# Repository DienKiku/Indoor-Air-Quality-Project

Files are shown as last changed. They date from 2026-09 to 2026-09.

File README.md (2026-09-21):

# Indoor Air Quality (IAQ) & Energy Monitoring IoT System






An edge-computing Internet of Things (IoT) station designed for real-time indoor environmental quality monitoring and autonomous power management. Powered by an ultra-compact **ESP32-C3 Super Mini (RISC-V)** microcontroller, the device integrates multi-sensor environmental sensing (PM2.5, VOC, Temperature, Humidity, Pressure), on-device visual feedback (1.8" ST7735 TFT), local acoustic alerts, a rechargeable 2S Li-ion battery subsystem with real-time power telemetry (INA219), and cloud synchronization with **Google Firebase**.

---

## 1. System Architecture

The project follows a modular **Three-Tier IoT Architecture**:

```mermaid
flowchart TD
    subgraph Tier1["Tier 1: Sensor & Edge Node (ESP32-C3 Super Mini)"]
        Sensors["Sensors:<br/>- BME680 (Temp, Hum, Press, Gas/VOC via I2C)<br/>- Sharp GP2Y1010AU0F (PM2.5 Dust via ADC + I-LED)<br/>- INA219 (Battery V, I, P via I2C)"]
        MCU["ESP32-C3 Super Mini<br/>(32-bit RISC-V @ 160MHz, 4MB Flash)"]
        Display["1.8-inch ST7735 TFT Display (SPI)"]
        Alert["TMB09A05 5V Buzzer (GPIO)"]
        PowerSubsystem["2S Li-ion Battery (2x 18650 2600mAh)<br/>- 2S 5A BMS Protection<br/>- Type-C 2S Boost Charger (8.4V)<br/>- AMS1117-5.0V LDO Regulator"]
        
        PowerSubsystem -->|"7.4V - 8.4V"| INA219
        INA219 -->|"V_bus / I_shunt"| AMS1117
        AMS1117 -->|"5.0V"| MCU
        AMS1117 -->|"5.0V"| Alert
        AMS1117 -->|"5.0V"| Sensors
        Sensors -->|"Data"| MCU
        MCU -->|"Render UI"| Display
        MCU -->|"Acoustic Alarm"| Alert
    end

    subgraph Tier2["Tier 2: Cloud Middleware (Google Firebase)"]
        FirebaseRTDB[("Firebase Realtime Database<br/>(NoSQL JSON Tree)")]
        FirebaseAuth["Firebase Authentication<br/>(Token / Database Secret)"]
        FirebaseHosting["Firebase Hosting / CDN"]
        FirebaseRTDB --- FirebaseAuth
    end

    subgraph Tier3["Tier 3: User Dashboard & Presentation"]
        WebDashboard["Web Application Dashboard<br/>- Real-time Gauges & Charts<br/>- Battery Health & Power Draw<br/>- Pollution & Threshold Alerts"]
        MobileView["Responsive Mobile UI"]
    end

    MCU -->|"Wi-Fi 802.11 b/g/n / HTTPS / WSS"| FirebaseRTDB
    FirebaseRTDB -->|"WebSocket Real-time Stream"| WebDashboard
    FirebaseRTDB -->|"WebSocket Real-time Stream"| MobileView
```

---

## 2. Hardware Bill of Materials (BOM)

| Component | Specification / Model | Interface | Function / Purpose |
| :--- | :--- | :--- | :--- |
| **Microcontroller (MCU)** | ESP32-C3 Super Mini (4MB Flash, RISC-V @ 160MHz) | Wi-Fi / BLE | Core controller, sensor aggregation, cloud comms |
| **Environmental Sensor** | Bosch BME680 | I2C (0x77 / 0x76) | Ambient Temp, Relative Humidity, Pressure, Gas/VOC |
| **Particulate Sensor** | Sharp GP2Y1010AU0F | Analog ADC + Digital GPIO | PM2.5 Optical Dust Density detection |
| **Energy Monitor** | INA219 MCU-219 | I2C (0x40) | 2S Battery bus voltage, discharge current, power draw |
| **Display** | 1.8-inch TFT LCD (ST7735 controller, 128x160) | SPI | Local graphical dashboard and status readouts |
| **Acoustic Indicator** | TMB09A05 5V Active Buzzer (9x5.5mm) | GPIO (via Transistor) | Audible alarms for hazardous IAQ and low battery |
| **Battery Cells** | 2x 18650 Li-ion Cells (2600 mAh each in 2S1P) | Battery Holder | Portable power source (Nominal: 7.4V, Full: 8.4V) |
| **Battery Management** | 2S 5A Lithium Protection Board (BMS) | Direct Battery | Overcharge, over-discharge, overcurrent & short-circuit protection |
| **Charger Board** | Type-C 3-6V to 2S-2A (8.4V) Boost Charger | USB Type-C | Fast, universal USB-C charging for 2S pack |
| **Voltage Regulator** | AMS1117-5.0V LDO Module | Power Rail | Steps down 7.4-8.4V battery output to stable 5.0V |

---

## 3. Hardware Circuit Schematic

The circuit schematic has been designed in KiCad and verified on physical prototype board:

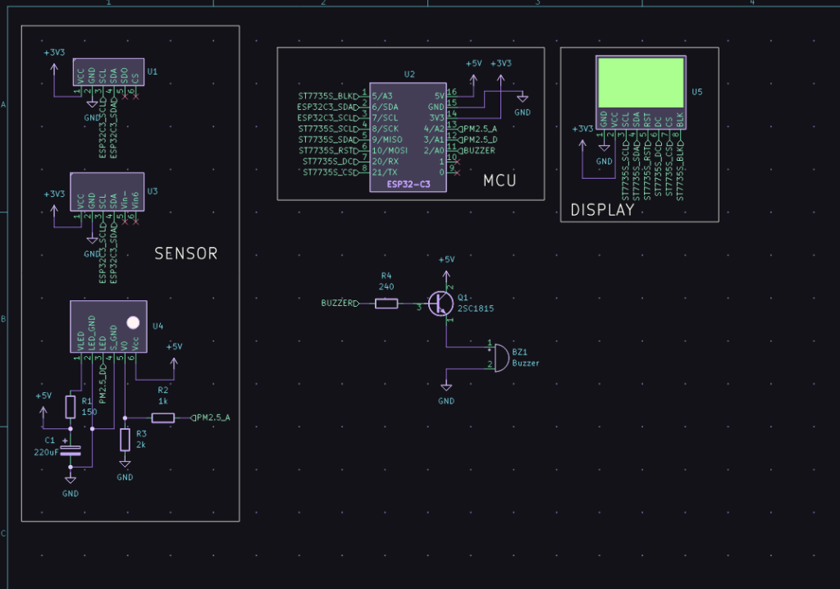
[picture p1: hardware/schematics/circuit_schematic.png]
Hardware Circuit Schematic


> **KiCad Design Source Files:** Available in [`hardware/schematics/`](hardware/schematics/) (`1.kicad_sch`, `1.kicad_pro`, `New_Library_1.kicad_sym`).

---

## 4. Repository Structure & Documentation

This repository is organized into distinct functional directories:

```text
├── hardware/
│   └── schematics/                # KiCad CAD schematic & visual diagram
│       ├── 1.kicad_sch            # KiCad schematic source file
│       ├── 1.kicad_pro            # KiCad project file
│       └── circuit_schematic.png  # Rendered KiCad schematic image
├── docs/
│   ├── system-spec/               # Technical system specifications
│   │   ├── 01_system_architecture.md
│   │   ├── 02_hardware_specification.md
│   │   ├── 03_circuit_and_pinout.md
│   │   ├── 04_software_and_cloud_spec.md
│   │   └── 05_power_management.md
│   ├── roadmap/                   # Project planning, Gantt, and RACI
│   │   ├── timeline_and_milestones.md
│   │   ├── task_assignment_raci.md
│   │   └── progress_tracker.md
│   ├── weekly-reports/            # Weekly progress tracking
│   │   ├── week-01.md
│   │   ├── week-02.md
│   │   └── week-03.md
│   └── reports/                   # Academic & Engineering Project Reports
│       ├── chapter_1_introduction.md
│       ├── chapter_2_theoretical_background.md
│       ├── chapter_3_hardware_software_design.md
│       ├── chapter_4_implementation_testing.md
│       └── chapter_5_conclusion_future_work.md
└── src/
    ├── firmware/                  # ESP32-C3 Arduino firmware (firmware.ino, firebase_config.h)
    ├── cloud-firebase/            # Firebase RTDB rules and sample telemetry schemas
    └── frontend/                  # Web Dashboard application (HTML5/CSS3/JS, Chart.js)
```

---

## 5. Software & Cloud Subsystems

- **ESP32-C3 Firmware ([`src/firmware/`](src/firmware/)):** The core firmware sketch ([`firmware.ino`](src/firmware/firmware.ino)) coordinates sensor acquisitions, ST7735 TFT graphical rendering (4-panel UI), 2S battery gauge monitoring, acoustic alarm triggering, and configured credentials ([`firebase_config.h`](src/firmware/firebase_config.h)). Can be edited and flashed using Arduino IDE or PlatformIO.
- **Cloud Backend ([`src/cloud-firebase/`](src/cloud-firebase/)):** Google Firebase Realtime Database schema and security rules for real-time station telemetry streaming.
- **User Web Dashboard ([`src/frontend/`](src/frontend/)):** Real-time monitoring dashboard ([`index.html`](src/frontend/index.html)) with live Chart.js trend visualization directly synced via Firebase WebSocket.

---

## 6. License
This project is licensed under the MIT License - see the [LICENSE](LICENSE) file for details.

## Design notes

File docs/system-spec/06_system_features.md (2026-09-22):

# System Features Specification

## 1. Indoor Air Quality (IAQ) Sensing Features
* **Real-time PM2.5 Fine Particulate Monitoring:**
  * Uses the Sharp GP2Y1010AU0F optical dust sensor[cite: 1].
  * Microsecond-accurate pulse driving circuit triggering an internal infrared LED with a $0.28\text{ ms}$ sampling window over a $0.32\text{ ms}$ cycle[cite: 1].
  * Internal analog-to-digital conversion (ADC) paired with a 10-sample moving average filter to suppress high-frequency noise and output dust density in $\mu\text{g/m}^3$.
* **Volatile Organic Compounds (VOC) & Gas Resistance Detection:**
  * Uses the Bosch BME680 sensor via standard I2C communication[cite: 1].
  * Dynamic metal-oxide (MOX) heated plate resistance measurement ($k\Omega$) for identifying smoke, solvent vapors, and gaseous pollutants[cite: 1].
* **Indoor Climate Telemetry (Temperature, Humidity, Pressure):**
  * Factory-calibrated ambient environmental acquisition via BME680 with high-precision outputs: temperature ($^\circ\text{C}$), relative humidity ($\%RH$), and barometric pressure ($\text{hPa}$)[cite: 1].

---

## 2. Power Subsystem & Energy Monitoring Features
* **Autonomous 2S Li-ion Battery Architecture:**
  * Powered by dual 18650 lithium-ion cells integrated with a 2S 5A BMS protection module against overcharge, over-discharge, and short circuits[cite: 1].
  * On-board Type-C 2S boost charging circuit supporting mobile charging up to $8.4\text{ V}$[cite: 1].
  * Regulated system bus powered via an AMS1117-5.0V low-dropout voltage regulator[cite: 1].
* **Real-time Battery Fuel Gauge & Power Profiling:**
  * High-side energy monitoring using the INA219 sensor via I2C (`0x40`)[cite: 1].
  * Real-time acquisition of bus voltage ($V$), shunt drop, and instantaneous discharge current ($mA$)[cite: 1].
  * Software-calculated battery State-of-Charge (SoC \%) and operating power consumption ($mW$)[cite: 1].

---

## 3. Local Graphical Display & Acoustic Alerting Features
* **Local Telemetry Dashboard (ST7735 1.8" TFT):**
  * Hardware 4-wire SPI graphical interface with dynamic UI partitioning[cite: 1].
  * 4-quadrant layout displaying: Temperature, Humidity, PM2.5 Dust Level, and VOC/Gas Index.
  * Real-time battery status icon with dynamic color coding based on charge level[cite: 1].
* **Multi-stage Acoustic Alarm System:**
  * Driven by a 5V active buzzer triggered via an NPN transistor switching circuit[cite: 1].
  * System startup and initialization feedback chirp[cite: 1].
  * Configurable acoustic alarm thresholds for dangerous PM2.5 concentrations, critical VOC levels, and low battery voltage[cite: 1].

---

## 4. Cloud Integration & Web Dashboard Features
* **Cloud Telemetry Streaming (Google Firebase):**
  * Automatic 2.4 GHz Wi-Fi connectivity on the ESP32-C3 with resilient auto-reconnect handling[cite: 1].
  * Structured JSON payload synchronization to Google Firebase Realtime Database (RTDB) every 5 seconds[cite: 1].
* **Interactive Responsive Web Dashboard:**
  * Browser-based user interface engineered using HTML5, CSS3, and modern vanilla JavaScript[cite: 1].
  * WebSocket real-time data streaming via the Firebase Web SDK for zero-refresh telemetry updates[cite: 1].
  * Dynamic time-series telemetry visualization utilizing Chart.js[cite: 1].
  * Historical trend analysis for ambient temperature, humidity, particulate density, and battery discharge curves.

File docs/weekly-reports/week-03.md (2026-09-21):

# Weekly Progress Report: Week 03

**Reporting Period:** 2026-09-15 to 2026-09-21  
**Project Name:** Indoor Air Quality (IAQ) & Energy Monitoring IoT System  
**Phase:** Phase 2: Hardware Prototyping & Sensor Validation  

---

## 1. Executive Summary
Week 03 achieved significant engineering milestones across hardware prototyping, electronic schematic capture, and offline firmware verification. A physical prototype circuit board was assembled and wired. The complete system schematic was designed in KiCad (`1.kicad_sch`) with custom footprint and symbol definitions. Offline firmware was developed and successfully executed on the hardware (`src/firmware/firmware.ino`), driving the 1.8-inch ST7735 TFT LCD with a custom 4-panel dashboard layout, active buzzer acoustics, and real-time telemetry from the Bosch BME680, Sharp GP2Y1010AU0F, and INA219 energy monitor.

---

## 2. Objectives for the Week
- [x] **Objective 1:** Assemble and wire the physical prototype circuit board.
- [x] **Objective 2:** Design and finalize the complete hardware schematic using KiCad.
- [x] **Objective 3:** Implement and validate standalone offline test firmware on the ESP32-C3.
- [x] **Objective 4:** Verify sensor data acquisition and graphical UI rendering on the 1.8" ST7735 TFT display.
- [x] **Objective 5:** Calibrate optical dust sensing with hardware scaling and validate INA219 power telemetry.
- [x] **Objective 6:** Prepare Google Firebase cloud schema and client configuration for Phase 3.

---

## 3. Accomplishments & Key Deliverables

### 3.1. Hardware Prototyping & KiCad Schematic
- Assembled the physical prototype board connecting:
  - ESP32-C3 Super Mini microcontroller.
  - Bosch BME680 (I2C: SDA on GPIO6, SCL on GPIO7).
  - INA219 Power Monitor (I2C: SDA on GPIO6, SCL on GPIO7).
  - Sharp GP2Y1010AU0F (IRED drive on GPIO3, Vo analog on GPIO4).
  - 1.8-inch ST7735 TFT LCD (SPI: CS on GPIO21, DC on GPIO20, RST on GPIO10, MOSI on GPIO9, SCLK on GPIO8, BL on GPIO5).
  - Acoustic Buzzer circuit driven by a 2SC1815 NPN transistor via GPIO2.
- Authored the complete electronic schematic in KiCad (`hardware/schematics/1.kicad_sch`, `1.kicad_pro`, `New_Library_1.kicad_sym`).
- Rendered high-resolution visual circuit diagram (`hardware/schematics/circuit_schematic.png`) for repository inspection.

### 3.2. Offline Test Firmware & Graphical UI
- Developed and verified `src/firmware/firmware.ino` on physical hardware:
  - Startup splash screen with system initialization check.
  - Acoustic double-chirp notification on boot (`BUZZER_PIN`).
  - 4-panel graphical layout on 128x160 TFT:
    - **TEMP Panel:** Displays temperature in °C; highlights RED (`COLOR_WARN`) when $> 35^\circ\text{C}$.
    - **HUMI Panel:** Displays relative humidity in %RH with green status.
    - **PM2.5 Panel:** Displays particulate mass concentration in $mg/m^3$; triggers alarm when $> 0.15 \, mg/m^3$.
    - **GAS Panel:** Displays BME680 gas resistance in $k\Omega$.
  - Bottom energy telemetry bar: Displays battery voltage (e.g., $7.9\text{V}$), discharge current (e.g., $88\text{mA}$), and dynamically draws a graphical 2S battery cell icon filled according to calculated SoC percentage.

### 3.3. Sensor Signal Calibration
- Integrated a $1.5\times$ scaling factor for the optical dust sensor analog output to account for the hardware resistor divider protecting the ESP32-C3 ADC.
- Implemented a 5-sample smoothing filter with $280\mu s$ pulse delay and $40\mu s$ sampling window.
- Formulated linear 2S State-of-Charge (SoC) calculation ($6.0\text{V} - 8.4\text{V}$).

---

## 4. Key Metrics & Test Results

| Test Scenario | Target Parameter | Measured Value | Result |
| :--- | :--- | :--- | :---: |
| **I2C Bus Scan** | BME680 & INA219 detection | Both devices acknowledged | **PASS** |
| **Display SPI Clock** | ST7735 rendering speed | Clean frame update @ 2s interval | **PASS** |
| **Optical Dust Sensor** | Baseline voltage in ambient air | $\approx 0.6V - 0.9V$ scaled | **PASS** |
| **Power Telemetry** | INA219 bus voltage reading | Matches multimeter within $\pm 0.02V$ | **PASS** |
| **Acoustic Alarm** | Buzzer trigger on $PM_{2.5} > 0.15$ | Sounds $200ms$ warning beep | **PASS** |

---

## 5. Challenges, Impediments & Mitigations

| Challenge / Issue | Root Cause | Mitigation / Solution |
| :--- | :--- | :--- |
| **Dust sensor Vo exceeding 3.3V** | Sharp GP2Y1010AU0F runs at 5V, outputting up to ~4.5V under heavy dust | Added a resistor voltage divider to step down the signal to $\le 3.3V$, and added a $1.5\times$ software correction factor in ADC calculation. |
| **LaTeX KaTeX error on GitHub** | MathJax parse conflict with unescaped `%` and multi-line `cases` in documentation | Re-formulated the SoC equation as a compact clamped piecewise formula, ensuring 100% flawless GitHub rendering. |

---

## 6. Objectives for Next Week (Week 04)
- [ ] **Objective 1:** Connect ESP32-C3 to local Wi-Fi and establish real-time link with Google Firebase Realtime Database.
- [ ] **Objective 2:** Configure Firebase project credentials (`FIREBASE_HOST`, `FIREBASE_AUTH`) and verify cloud JSON payload delivery.
- [ ] **Objective 3:** Integrate Firebase cloud data synchronization into the primary firmware sketch (`src/firmware/firmware.ino`).
- [ ] **Objective 4:** Test initial Web Dashboard connection to Firebase Realtime Database stream.

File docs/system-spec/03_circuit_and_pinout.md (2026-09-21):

# 03. Circuit Schematics & Pinout Mapping

## 1. Visual Circuit Schematic Diagram

Below is the complete hardware schematic diagram generated from the verified KiCad engineering schematic (`hardware/schematics/1.kicad_sch`):

Hardware Circuit Schematic

---

## 2. Verified Pin Assignment Table

The hardware prototype board connects the ESP32-C3 Super Mini to all peripherals using the verified pin mapping below:

| ESP32-C3 Pin | Connected Peripheral | Peripheral Pin | Interface / Protocol | Functional Description |
| :--- | :--- | :--- | :--- | :--- |
| **GPIO 6** | BME680 & INA219 | SDA | Hardware I2C (SDA) | Shared bi-directional I2C serial data line |
| **GPIO 7** | BME680 & INA219 | SCL | Hardware I2C (SCL) | Shared I2C serial clock line |
| **GPIO 9** | 1.8" ST7735 TFT | SDA / MOSI | Hardware SPI (MOSI) | Serial display pixel data input |
| **GPIO 8** | 1.8" ST7735 TFT | SCL / SCK | Hardware SPI (SCK) | Serial display clock signal |
| **GPIO 21** | 1.8" ST7735 TFT | CS | Digital Output (SPI CS) | Display active-low chip select |
| **GPIO 20** | 1.8" ST7735 TFT | DC / A0 | Digital Output (Data/Cmd)| Data/Command selection pin |
| **GPIO 10** | 1.8" ST7735 TFT | RES / RST | Digital Output (Reset) | Display hardware reset line |
| **GPIO 5** | 1.8" ST7735 TFT | BLK / LED | Digital Output / PWM | Backlight enable & brightness control |
| **GPIO 3** | Sharp GP2Y1010AU0F | Pin 3 (LED) | Digital Output (Active LOW)| Pulses infrared emitting diode (IRED) |
| **GPIO 4** | Sharp GP2Y1010AU0F | Pin 5 ($V_o$) | Analog Input (ADC1_CH4) | Scaled analog voltage from optical dust chamber |
| **GPIO 2** | Acoustic Buzzer Circuit| Base of Q1 (2SC1815)| Digital Output (HIGH=ON)| Drives active buzzer via NPN transistor |
| **5V (VIN)** | AMS1117-5.0V LDO | VOUT | Power Input (+5.0V) | Main regulated power rail to MCU board |
| **3.3V** | BME680, INA219, TFT | VCC / VDD | Power Rail (+3.3V) | Logic supply rail from ESP32-C3 onboard LDO |
| **GND** | All Modules | GND | Common System Ground | Common 0V reference ground across all circuits |

---

## 3. Sensor Interfacing Schematics

### 3.1. Sharp GP2Y1010AU0F Wiring
The Sharp GP2Y1010AU0F requires an external RC pulse driving network and a voltage divider:
- **Pin 1 ($V_{LED}$):** Connected to +5V through a $150 \Omega$ or $240 \Omega$ current-limiting resistor with a $220 \mu F$ bypass capacitor to GND.
- **Pin 2 ($LED\text{-}GND$):** Connected to Common GND.
- **Pin 3 ($LED$):** Connected to ESP32-C3 **GPIO 3** (`DUST_LED_PIN`). Driven LOW for $280\mu s$ before ADC sampling.
- **Pin 4 ($S\text{-}GND$):** Connected to Common GND.
- **Pin 5 ($V_o$):** Analog output voltage, routed through a resistive voltage divider to scale to $\le 3.3V$ and read via ESP32-C3 **GPIO 4** (`DUST_VO_PIN`).
- **Pin 6 ($V_{cc}$):** Connected to +5V regulated rail.

```
       +5V Rail -------------------+
                                   |
                                 [150R]
                                   |
                                   +------- Pin 1 (V_LED)
                                   |
                                 [220uF]
                                   |
       GND ------------------------+------- Pin 2 (LED-GND)
                                   |
       ESP32-C3 GPIO 1 -------------------- Pin 3 (LED Drive)
       GND -------------------------------- Pin 4 (S-GND)
       ESP32-C3 GPIO 0 (ADC) -------------- Pin 5 (V_o Output)
       +5V Rail --------------------------- Pin 6 (V_cc)
```

### 2.2. INA219 Power Sense Wiring
- **VIN+:** Connected to the positive terminal of the 2S 5A BMS output ($7.4V - 8.4V$).
- **VIN-:** Connected to the input of the AMS1117-5.0V voltage regulator.
- **VCC:** Connected to 3.3V rail.
- **GND:** Connected to Common GND.
- **SDA:** Connected to ESP32-C3 **GPIO 8**.
- **SCL:** Connected to ESP32-C3 **GPIO 9**.

### 2.3. Active Buzzer Circuit (TMB09A05)
Because the ESP32-C3 GPIO pins supply up to ~20 mA at 3.3V and the TMB09A05 requires 5V with ~30-40 mA peak current, an NPN switching transistor (2N2222 or SS8050) is used:
- **Collector:** Connected to Buzzer negative pin (-).
- **Buzzer positive pin (+):** Connected to +5V rail.
- **Emitter:** Connected to Common GND.
- **Base:** Connected to ESP32-C3 **GPIO 2** through a $1 k\Omega$ current-limiting resistor.
- A flyback diode (1N4148) is placed in anti-parallel across the buzzer terminals to suppress inductive voltage spikes.

---

## 3. Power Distribution Diagram

```
[USB Type-C 5V Input]
         |
         v
[Type-C to 2S 8.4V Boost Charger]
         |
         v
[2x 18650 Li-ion Cells (2S1P)] <---> [2S 5A BMS Board]
                                              |
                                              v  Pack Output (7.4V - 8.4V)
                                       [INA219 Sense (VIN+ -> VIN-)]
                                              |
                                              v
                                      [AMS1117-5.0V Module]
                                              |
                      +-----------------------+-----------------------+
                      | 5.0V Rail                                     | 5.0V Rail
                      v                                               v
            [ESP32-C3 VIN pin]                             [GP2Y1010AU0F & Buzzer]
                      |
                      v (On-board LDO)
                 3.3V Logic Rail
                      |
        +-------------+-------------+
        |                           |
        v                           v
  [Bosch BME680]          [ST7735 1.8" TFT]
```

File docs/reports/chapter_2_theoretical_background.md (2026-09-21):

# Chapter 2: Theoretical Background & System Design

## 2.1. Indoor Air Quality (IAQ) Metrics & International Standards

Indoor Air Quality (IAQ) refers to the chemical, physical, and biological characteristics of air within buildings and structures as they relate to the health, comfort, and productivity of occupants. Evaluating IAQ requires quantifying multiple independent airborne metrics against established environmental health guidelines.

### 2.1.1. Fine Particulate Matter ($PM_{2.5}$ and $PM_{10}$)
Particulate matter represents a complex mixture of microscopic solid particles and liquid droplets suspended in the air. Particles are categorized by their aerodynamic diameter:
- **Coarse Particulates ($PM_{10}$):** Particles with diameters between $2.5 \, \mu m$ and $10 \, \mu m$ (e.g., pollen, coarse dust, mold spores).
- **Fine Particulates ($PM_{2.5}$):** Particles with aerodynamic diameters $\le 2.5 \, \mu m$ (e.g., combustion particles, organic compounds, heavy metals).

Because $PM_{2.5}$ particles remain suspended in ambient air for prolonged durations and readily penetrate deep into the alveolar regions of the human respiratory system, international regulatory bodies enforce stringent thresholds. The World Health Organization (WHO) and the United States Environmental Protection Agency (US-EPA) define air quality rating categories based on 24-hour average $PM_{2.5}$ concentrations:

| EPA Air Quality Category | $PM_{2.5}$ Concentration Range ($\mu g/m^3$) | Health Implications for Occupants |
| :--- | :---: | :--- |
| **Good** | $0.0 - 12.0$ | Air quality is considered satisfactory; air pollution poses little or no risk. |
| **Moderate** | $12.1 - 35.4$ | Acceptable air quality; slight risk for unusually sensitive individuals. |
| **Unhealthy for Sensitive Groups** | $35.5 - 55.4$ | Members of sensitive groups may experience respiratory irritation. |
| **Unhealthy** | $55.5 - 150.4$ | General public may begin to experience health effects; sensitive groups affected more severely. |
| **Very Unhealthy / Hazardous** | $\ge 150.5$ | Health alert: serious risk of respiratory and cardiovascular impairment for all occupants. |

### 2.1.2. Volatile Organic Compounds (VOCs)
Volatile Organic Compounds encompass a diverse class of carbon-based chemicals exhibiting high vapor pressure under standard room temperatures ($20^\circ C - 25^\circ C$). Common indoor VOCs include formaldehyde ($HCHO$), benzene ($C_6H_6$), toluene, and ethanol. Total Volatile Organic Compound (TVOC) concentration serves as a vital index for chemical indoor air quality. Prolonged exposure causes irritation of the eyes and respiratory tract, chronic headaches, and increased long-term oncological risks.

### 2.1.3. Microclimate Variables: Temperature, Humidity, and Pressure
Ambient thermal parameters directly influence chemical off-gassing rates and biological contamination:
- **Temperature ($T$):** Elevated indoor temperatures accelerate the evaporation and emission rates of VOCs from building materials.
- **Relative Humidity ($RH$):** High humidity ($RH > 65\%$) creates an ideal environment for mold propagation, dust mite proliferation, and bacterial colonization, whereas low humidity ($RH < 30\%$) irritates respiratory mucous membranes.
- **Barometric Pressure ($P$):** Atmospheric pressure gradients govern air infiltration rates between indoor zones and outdoor air.

---

## 2.2. Sensing Principles & Transducer Technologies

### 2.2.1. Optical Particulate Detection: Sharp GP2Y1010AU0F
The Sharp GP2Y1010AU0F dust sensor employs the **light scattering principle**. Inside the optical chamber, an Infrared Emitting Diode (IRED) and a phototransistor are positioned diagonally.

```
       [IRED Pulse Generator] 
                 \
                  \  Incident IR Beam (lambda = 850nm)
                   \
               [Dust Particles] ---> Scattered Light Rays
                     \
                      \  Scattered Beam
                       v
              [Phototransistor Receiver]
                       |
                       v
         [Signal Conditioning Amplifier]
                       |
                       v
           Analog Output Voltage (V_o)
```

1. **Pulse Activation:** When the internal IRED is pulsed with a narrow forward current pulse, an infrared light beam traverses the sensing chamber.
2. **Rayleigh/Mie Scattering:** Suspended dust particles crossing the optical path scatter light at an angle proportional to particle surface area and density.
3. **Phototransistor Detection:** The phototransistor collects a portion of the scattered light, generating a photocurrent that is internally amplified into an analog output voltage $V_o$.
4. **Timing Constraints:** To prevent thermal drift and minimize power consumption, the IRED must be pulsed with strict timing:
   - Pulse period $T = 10 \, ms$.
   - Pulse duration $\tau = 0.32 \, ms$ ($320 \, \mu s$).
   - Sampling instant $t_{sample} = 0.28 \, ms$ ($280 \, \mu s$) from pulse initiation.
5. **Transfer Function & Hardware Scaling:** Because the sensor output $V_o$ can reach $\approx 4.5V - 5.0V$, a resistive voltage divider steps the signal down to the ESP32-C3 ADC range ($\le 3.3V$), introducing a scaling correction factor of $1.5\times$:
   $$V_{Vo} = V_{ADC} \times 1.5$$
   The calibrated particulate mass concentration $D$ (in $\text{mg/m}^3$) is calculated as:
   $$D \, (\text{mg/m}^3) = \max\left(0.0, \; 0.17 \times V_{Vo} - 0.1\right)$$
   and converted to standard $\mu\text{g/m}^3$ via:
   $$D \, (\mu\text{g/m}^3) = D \, (\text{mg/m}^3) \times 1000$$

### 2.2.2. Metal Oxide Semiconductor (MOX) Gas Sensing: Bosch BME680
The BME680 integrates an ambient temperature sensor, capacitive humidity sensor, piezoresistive barometric pressure sensor, and a metal-oxide (MOX) gas sensor onto a single monolithic silicon die.

- **Operating Principle:** The gas sensor utilizes a heated thin-film layer of metal oxide semiconductor (typically tin dioxide, $SnO_2$). In clean ambient air, atmospheric oxygen molecules adsorb onto the $SnO_2$ crystal surface, capturing conduction-band electrons to form negative surface oxygen ions ($O^-, O_2^-$). This forms a high-resistance potential barrier at inter-grain boundaries:
  $$O_2(gas) + 2e^- \rightarrow 2O^-(ads)$$
- **Reaction with Reducing VOC Gases:** When volatile organic compounds (e.g., ethanol, formaldehyde, carbon monoxide) contact the heated metal-oxide surface ($300^\circ C - 320^\circ C$), they react with the adsorbed oxygen ions, releasing captured electrons back into the conduction band:
  $$R\text{-}H + O^-(ads) \rightarrow R\text{-}OH + e^-$$
- **Resistance Reduction:** This electron release diminishes the potential barrier, causing a sharp reduction in electrical resistance across the sensor film ($R_{gas}$). The measured resistance $R_{gas}$ is inversely related to VOC concentration.

### 2.2.3. High-Side Shunt Energy Monitoring: INA219
The Texas Instruments INA219 is a high-side current shunt and power monitor with an I2C interface.

```
       V_bat (+) ------+--------------------+------ Load Rail (AMS1117-5.0V)
                       |                    |
                     [VIN+]               [VIN-]
                       |                    |
                       +-----[ R_shunt ]----+  (R_shunt = 0.1 Ohm)
                                  |
                                  v
                     [Differential PGA (x1 - x8)]
                                  |
                                  v
                     [12-bit Delta-Sigma ADC]
                                  |
                                  v
                     [Internal Digital Multiplier]
                                  |
                                  v
                        [I2C Register Interface]
```

- **Shunt Voltage Measurement:** Measures the differential voltage drop across a precision shunt resistor ($R_{shunt} = 0.1 \, \Omega$, 1% tolerance) inserted in series between the battery positive terminal and the load:
  $$V_{shunt} = V_{IN+} - V_{IN-}$$
- **Current Derivation:** Current is computed digitally inside the INA219:
  $$I = \frac{V_{shunt}}{R_{shunt}}$$
- **Bus Voltage Measurement:** The voltage between the $V_{IN-}$ pin and system ground ($GND$) represents the actual battery bus voltage $V_{bus}$.
- **Power Derivation:** Instantaneous system power is calculated as:
  $$P = V_{bus} \times I$$

---

## 2.3. Microcontroller Architecture: ESP32-C3 Super Mini

The central processing unit of the monitoring station is the **ESP32-C3 Super Mini**, an ultra-low-power, high-performance System-on-Chip (SoC) developed by Espressif Systems:
- **Processor Core:** 32-bit RISC-V single-core microprocessor (RV32IMC instruction set architecture) operating at clock frequencies up to $160 \, MHz$.
- **Memory Subsystem:**
  - $400 \, KB$ of internal SRAM for data storage and dynamic memory allocation.
  - $384 \, KB$ of internal ROM for booting and core library routines.
  - $4 \, MB$ of external Quad-SPI Flash memory integrated on-module for firmware code, assets, and configuration.
- **Wireless Networking:**
  - Integrated 2.4 GHz Wi-Fi subsystem compliant with IEEE 802.11 b/g/n, supporting HT20/HT40 bandwidths with data rates up to $150 \, Mbps$.
  - Bluetooth 5 (LE) supporting 2 Mbps PHY, long range, and broadcast advertising.
- **Integrated Hardware Peripherals:**
  - 12-bit Successive Approximation Register (SAR) Analog-to-Digital Converter (ADC) across multiple channels.
  - Hardware I2C master controller supporting standard ($100 \, kHz$) and fast ($400 \, kHz$) modes.
  - General-Purpose SPI controller capable of high-speed transmission up to $40 \, MHz$, critical for smooth TFT display refreshing.
  - General-Purpose Input/Output (GPIO) matrix with configurable pull-up, pull-down, and drive strengths.

---

## 2.4. Cloud Middleware & Synchronization: Google Firebase

To deliver real-time data streaming and remote dashboard access without managing dedicated server infrastructure, the platform leverages **Google Firebase**:

```
[ESP32-C3 Edge Node] 
        |
        | Secure TLS / HTTPS / WebSocket Stream
        v
[Firebase Realtime Database (RTDB)] <--- NoSQL JSON Tree
        |
        | Server-Sent Events (SSE) / WebSocket Push
        v
[Client Web Dashboard (HTML5/JS)]
```

1. **Firebase Realtime Database (RTDB):** A cloud-hosted NoSQL document database where data is structured as a single hierarchical JSON tree. Unlike traditional SQL databases that require polling, Firebase pushes updates to connected clients in real time over persistent WebSocket connections.
2. **Low-Latency Bi-Directional Synchronization:** When the ESP32-C3 executes a `setJSON()` or `updateNode()` operation, the updated environmental state is propagated to all open web dashboard instances within milliseconds.
3. **Offline Caching & Data Resiliency:** The client-side Firebase JavaScript SDK provides local caching capabilities, maintaining seamless dashboard interactivity during intermittent network disconnects.
4. **Security Enforcement:** Declarative JSON security rules govern read/write permissions, validating that incoming sensor payloads adhere to expected schema definitions and type constraints.

---

## 2.5. Autonomous Power Subsystem & Energy Modeling

### 2.5.1. 2S Li-ion Battery Configuration
To provide untethered mobility, the system is powered by two cylindrical Lithium-ion 18650 cells connected in series (2S1P configuration):
- **Nominal Pack Voltage:** $2 \times 3.7V = 7.4V$.
- **Full Charge Pack Voltage:** $2 \times 4.2V = 8.4V$.
- **Cutoff / Depleted Pack Voltage:** $2 \times 3.0V = 6.0V$.
- **Nominal Cell Capacity:** $2600 \, mAh$ ($2.6 \, Ah$).
- **Total Pack Energy:**
  $$E = V_{nominal} \times C = 7.4V \times 2.6Ah = 19.24 \, \text{Wh}$$

### 2.5.2. Battery Management System (BMS 2S 5A)
Lithium-ion cells require active electronic protection against hazardous operating regimes:
- **Overcharge Cutoff ($V_{ovp}$):** $4.25V \pm 0.05V$ per cell. Disconnects charging current to prevent thermal runaway.
- **Over-discharge Cutoff ($V_{uvp}$):** $2.50V \pm 0.08V$ per cell. Disconnects the load to protect cell chemistry against irreversible copper dissolution.
- **Overcurrent Protection:** Automatically interrupts conduction if discharge current exceeds $10A$ peak or $5A$ continuous.

### 2.5.3. Type-C 2S Boost Charger (8.4V, 2A)
The charger board utilizes a high-efficiency synchronous boost switching converter:
- Converts standard $5.0V$ USB input (from smartphone chargers or power banks) up to the $8.4V$ required for 2S charging.
- Executes the standard two-phase **Constant Current / Constant Voltage (CC/CV)** charging profile:
  - **CC Phase:** Delivers up to $2.0A$ constant current while the pack voltage rises from $6.0V$ toward $8.4V$.
  - **CV Phase:** Maintains exactly $8.40V$ while charging current exponentially decays to the termination threshold ($C/10 \approx 200mA$).

### 2.5.4. Linear Voltage Regulation: AMS1117-5.0V
The AMS1117-5.0V Low Dropout (LDO) regulator steps down the variable battery pack voltage ($7.4V - 8.4V$) to a stable $5.0V$ rail:
- Supplies the Sharp GP2Y1010AU0F optical dust sensor ($5V \pm 10\%$).
- Supplies the TMB09A05 active buzzer ($5V$).
- Feeds the $VIN$ pin of the ESP32-C3 Super Mini, whose internal onboard LDO further steps down $5.0V$ to $3.3V$ for the RISC-V core, BME680, and ST7735 logic.
- **LDO Efficiency:**
  $$\eta_{LDO} = \frac{V_{out}}{V_{in}} = \frac{5.0V}{7.4V} \approx 67.5\% \quad (\text{at nominal battery voltage})$$
  Power dissipated as heat:
  $$P_{diss} = (V_{in} - V_{out}) \times I_{load} = (7.4V - 5.0V) \times 0.15A \approx 0.36 \, W$$

---

## 2.6. Proposed System Architecture & Design

The functional architecture integrates the sensing transducers, edge processing, visual/acoustic alerting, and cloud synchronization into an interdependent pipeline:

```mermaid
flowchart TD
    subgraph Power["Power Subsystem (2S)"]
        Bat["2x 18650 Li-ion Cells (7.4V)"] --> BMS["2S 5A BMS Board"]
        BMS --> INA["INA219 Current/Voltage Monitor"]
        INA --> LDO["AMS1117-5.0V Regulator"]
        LDO --> Rail5V["5.0V Power Rail"]
    end

    subgraph Sensing["Sensing Layer"]
        BME["Bosch BME680 (I2C)"]
        Dust["Sharp GP2Y1010AU0F (ADC/GPIO)"]
    end

    subgraph Processing["ESP32-C3 Super Mini Core"]
        Sample["Sensor Acquisition Loop"]
        Filter["Moving Average Filter & Baseline Tracker"]
        Eval["Threshold & IAQ Level Evaluation"]
        DisplayDriver["ST7735 SPI Display Driver"]
        CloudDriver["Firebase Client Sync Task"]
    end

    subgraph Output["Output & Presentation"]
        TFT["1.8-inch ST7735 TFT Display"]
        Buzzer["TMB09A05 Active Buzzer"]
        Firebase[("Google Firebase RTDB")]
        Dashboard["Web Application Dashboard"]
    end

    Rail5V --> Dust
    Rail5V --> Buzzer
    Rail5V --> Processing
    Processing -->|"3.3V Logic"| BME
    Processing -->|"3.3V Logic"| INA
    
    BME -->|"I2C: SDA/SCL"| Sample
    INA -->|"I2C: SDA/SCL"| Sample
    Dust -->|"Analog Vo & I-LED Pulse"| Sample
    
    Sample --> Filter --> Eval
    Eval --> DisplayDriver --> TFT
    Eval -->|"GPIO Trigger"| Buzzer
    Eval --> CloudDriver -->|"Wi-Fi / WSS"| Firebase
    Firebase -->|"WebSocket Push"| Dashboard
```

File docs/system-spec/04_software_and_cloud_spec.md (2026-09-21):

# 04. Software & Cloud Specification

## 1. Firmware Architecture (C/C++)

The firmware is developed using the **PlatformIO ecosystem** on the **Arduino Framework** for the ESP32-C3. The software executes a non-blocking, multi-interval scheduling loop to ensure timely sensor sampling, local rendering, and network synchronization.

```mermaid
stateDiagram-v2
    [*] --> Initialization
    Initialization --> SensorCalibration : I2C & SPI Init
    SensorCalibration --> WiFiConnect : Connect to 2.4GHz AP
    WiFiConnect --> FirebaseAuth : Initialize Firebase Client
    FirebaseAuth --> MainLoop : Start Scheduler

    state MainLoop {
        [*] --> CheckTimers
        CheckTimers --> SampleDust : Every 1000ms
        CheckTimers --> SampleBME680 : Every 2000ms
        CheckTimers --> SampleINA219 : Every 2000ms
        CheckTimers --> UpdateTFT : Every 1000ms
        CheckTimers --> SyncFirebase : Every 5000ms
        CheckTimers --> EvaluateAlerts : Immediate
    }
```

---

## 2. Sensor Signal Processing Algorithms

### 2.1. Sharp GP2Y1010AU0F Microsecond Timing & Calibration
The optical dust sensor requires microsecond-accurate pulse modulation to energize the infrared emitter diode (IRED) and sample the scattered light:

1. Drive `GPIO 3` (DUST_LED_PIN) LOW to activate the internal IRED.
2. Wait precisely $280 \mu s$ ($0.28 ms$) for the light pulse and optical reflection to stabilize.
3. Sample the analog voltage on `GPIO 4` (DUST_VO_PIN) using the ESP32-C3 12-bit ADC (`ADC_11db` attenuation, sampling duration $\approx 40 \mu s$).
4. Drive `GPIO 3` HIGH to deactivate the IRED (total pulse duration: $320 \mu s$).
5. Wait for $9680 \mu s$ to complete the standard $10 ms$ operating cycle.

#### Mathematical Conversion & Hardware Scaling:
The analog output $V_o$ from the GP2Y1010AU0F can reach up to $\approx 4.5V - 5.0V$. A hardware resistor voltage divider is placed at the analog pin to scale the signal to within the ESP32-C3 ADC range ($\le 3.3V$), introducing a scaling correction factor of $1.5$:

$$V_{raw} = \text{ADC\_Value} \times \left(\frac{3.3\text{V}}{4095}\right)$$
$$V_{Vo} = V_{raw} \times 1.5$$

Applying the calibrated Sharp linear transfer function:
$$\text{Dust Density } (\text{mg/m}^3) = \max\left(0.0, \; 0.17 \times V_{Vo} - 0.1\right)$$

To convert to standard $\mu g/m^3$:
$$\text{Dust Density } (\mu\text{g/m}^3) = \text{Dust Density } (\text{mg/m}^3) \times 1000$$

A **5-sample Moving Average Filter (MAF)** is applied to smooth instantaneous noise:
$$\bar{D} = \frac{1}{5} \sum_{i=1}^{5} D_i$$

### 2.2. BME680 Gas Resistance & IAQ Estimation
The BME680 incorporates a metal-oxide (MOX) gas sensor heated to 320°C for 150 ms before readout. Higher gas resistance ($R_{gas}$ in $k\Omega$) indicates cleaner air, while lower resistance corresponds to elevated volatile organic compounds (VOCs).

- **Gas Resistance Formula:**
  $$R_{gas} (\text{k}\Omega) = \frac{\text{raw\_resistance}}{1000.0}$$
- **Categorization:**
  - $R_{gas} \ge 150 \, k\Omega$: Good (clean indoor air).
  - $50 \, k\Omega \le R_{gas} < 150 \, k\Omega$: Moderate.
  - $R_{gas} < 50 \, k\Omega$: Hazardous (Elevated VOC / cooking smoke / solvent vapors).

### 2.3. Battery State-of-Charge (SoC) Calculation
The INA219 measures the 2S battery pack bus voltage ($V_{bus}$). The remaining capacity percentage is calculated using a linear interpolation across the 2S operational range ($6.0\text{V}$ cutoff to $8.4\text{V}$ fully charged):

$$\text{Battery SoC (\%)} = \min\left(100, \; \max\left(0, \; \frac{V_{bus} - 6.0\text{V}}{8.4\text{V} - 6.0\text{V}} \times 100\right)\right)$$

In the firmware implementation:
```cpp
float batteryPct = (busvoltage - 6.0) / (8.4 - 6.0) * 100.0;
if (batteryPct > 100) batteryPct = 100;
if (batteryPct < 0) batteryPct = 0;
```

---

## 3. Google Firebase Cloud Specification

### 3.1. Database Architecture
Data is synchronized to the **Firebase Realtime Database (RTDB)** using an optimized JSON hierarchical structure:

```json
{
  "iaq_stations": {
    "ESP32C3_STATION_01": {
      "metadata": {
        "firmware_version": "1.0.0",
        "device_name": "Living Room Monitor",
        "last_seen": 1726848000
      },
      "live_metrics": {
        "temperature_c": 26.4,
        "humidity_pct": 58.1,
        "pressure_hpa": 1013.2,
        "gas_resistance_kohm": 142.5,
        "pm25_ug_m3": 18.3,
        "iaq_grade": "GOOD",
        "timestamp": 1726848000
      },
      "power_telemetry": {
        "bus_voltage_v": 7.94,
        "current_ma": 92.6,
        "power_mw": 735.2,
        "battery_pct": 81,
        "charging_state": false
      },
      "alerts": {
        "active": false,
        "type": "NONE",
        "message": "Air quality is optimal."
      },
      "history": {
        "-O7x9A1b2c3d4e5f": {
          "timestamp": 1726848000,
          "pm25": 18.3,
          "voc_kohm": 142.5,
          "temp": 26.4,
          "hum": 58.1,
          "v_bat": 7.94
        }
      }
    }
  }
}
```

### 3.2. Firebase Security Rules
Granular rules enforce that the ESP32-C3 can only write to its designated station node while authenticated:

```json
{
  "rules": {
    "iaq_stations": {
      "$station_id": {
        ".read": true,
        ".write": "auth != null || auth.uid === $station_id"
      }
    }
  }
}
```

---

## 4. Alert & Threshold Logic

| Parameter | Operational Threshold | Hardware Trigger | UI & System Action |
| :--- | :--- | :--- | :--- |
| **PM2.5 Dust** | $> 0.15 \, \text{mg/m}^3$ ($150 \, \mu\text{g/m}^3$) | `dustDensity > 0.15` | TFT text turns RED (`COLOR_WARN`); Buzzer sounds alert beep ($200\text{ms}$) |
| **Battery SoC** | $< 20.0\%$ ($V_{bus} < 6.48\text{V}$) | `batteryPct < 20.0` | Battery icon turns RED; Buzzer sounds low-power warning |
| **Temperature** | $> 35.0^\circ\text{C}$ | `temp > 35.0` | Temperature reading turns RED (`COLOR_WARN`) |
| **BME680 VOC** | $< 50.0 \, \text{k}\Omega$ | Low gas resistance | Environmental quality status degrades on TFT |

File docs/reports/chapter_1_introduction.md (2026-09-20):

# Chapter 1: Introduction

## 1.1. Background & Problem Statement

In modern urbanized societies, humans spend approximately 85% to 90% of their daily lives inside enclosed environments—including residences, educational institutions, offices, and commercial spaces. Consequently, the quality of indoor air significantly dictates human health, respiratory well-being, cognitive performance, and overall quality of life.

Despite widespread public awareness regarding outdoor atmospheric smog and industrial emissions, empirical environmental studies consistently reveal that **indoor air pollutant concentrations can be two to five times—and in severe cases up to one hundred times—higher than outdoor levels**. Indoor environments accumulate diverse airborne pollutants emitted from:
- Cooking activities, biomass combustion, and tobacco smoke, which release hazardous **Fine Particulate Matter ($PM_{2.5}$ and $PM_{10}$)**.
- Building materials, synthetic paints, adhesives, varnishes, and cleaning detergents, which emit a wide spectrum of **Volatile Organic Compounds (VOCs)** such as formaldehyde, benzene, and toluene.
- Human respiration in inadequately ventilated spaces, resulting in elevated carbon dioxide ($CO_2$) and stagnant humidity, fostering microbial colonies and mold growth.

Inhalation of fine particles with aerodynamic diameters $\le 2.5 \, \mu m$ ($PM_{2.5}$) poses acute and chronic health risks. Due to their minute dimensions, $PM_{2.5}$ particles bypass upper respiratory filtration mechanisms, penetrating deep into the pulmonary alveoli and entering the systemic bloodstream. Long-term exposure correlates directly with chronic obstructive pulmonary disease (COPD), ischemic heart disease, stroke, and lung cancer. Concurrently, elevated concentrations of VOCs induce "Sick Building Syndrome" (SBS), characterized by headaches, mucous membrane irritation, fatigue, and impaired cognitive clarity.

---

## 1.2. Motivation & Significance

While commercial consumer air purifiers and standalone monitors exist on the market, they present several critical engineering and operational limitations:
1. **Proprietary Ecosystems & Data Silos:** Commercial units often restrict data access to proprietary cloud silos with closed communication protocols, precluding integration into open-source building management systems or customized analytical platforms.
2. **Limited Multi-Parameter Sensing:** Low-cost monitors typically detect only a single parameter (e.g., temperature and humidity, or dust alone), failing to deliver a holistic indoor air quality (IAQ) assessment that combines fine particulates, chemical gases (VOCs), and barometric microclimate variables.
3. **Lack of Autonomous Power Telemetry:** Portable monitoring nodes deployed in dynamic indoor environments require untethered battery operation. However, existing devices lack integrated high-precision power telemetry, leaving users unable to predict remaining runtime or manage energy consumption effectively.

To address these challenges, this project designs and implements an open, edge-computing **Indoor Air Quality (IAQ) and Energy Monitoring IoT System**. By combining an ultra-low-power 32-bit RISC-V microcontroller (ESP32-C3) with laboratory-grade multi-sensor instrumentation (Bosch BME680, Sharp GP2Y1010AU0F, INA219), a full-color graphical display (ST7735), an autonomous 2S Li-ion battery subsystem, and real-time cloud synchronization via **Google Firebase**, this system provides a comprehensive, cost-effective, and fully verifiable indoor environmental management solution.

---

## 1.3. Research Objectives & System Scope

### 1.3.1. Primary Objectives
The primary aim of this project is to develop, validate, and evaluate an autonomous, IoT-enabled indoor environmental monitoring station. Specific technical objectives include:
1. **Multi-Parameter Environmental Sensing:** Design and interface sensory circuits capable of measuring particulate matter ($PM_{2.5}$), total volatile organic compounds (VOC gas resistance), ambient temperature, relative humidity, and atmospheric pressure.
2. **Autonomous Power Management & Energy Telemetry:** Architect a self-contained 2S Li-ion battery power subsystem featuring overcharge/over-discharge protection (BMS), USB Type-C boost charging, linear voltage regulation, and real-time high-side current and voltage sensing via the INA219 transducer.
3. **Edge Signal Processing & Local Alerting:** Implement digital filtering algorithms (10-sample moving average) for analog optical dust sensing, dynamic baseline calibration for MOX gas resistance, on-device rendering on a 1.8-inch TFT LCD, and acoustic alarm generation for hazardous conditions.
4. **Real-time Cloud Integration & User Dashboard:** Establish secure Wi-Fi connectivity to synchronize telemetry data to Google Firebase Realtime Database and build a responsive Web Dashboard with live visual gauges, time-series charts, and historical analytics.

### 1.3.2. Scope and Delimitations
- **Deployment Domain:** The system is engineered for indoor domestic, office, and academic laboratory spaces (enclosed areas ranging from $15 \, m^2$ to $60 \, m^2$).
- **Target Particulate Range:** Optical detection of $PM_{2.5}$ dust concentrations between $0 \, \mu g/m^3$ and $500 \, \mu g/m^3$.
- **Target Microclimate Range:** Ambient temperature (-10°C to +60°C), relative humidity (10% to 90% RH), and barometric pressure (300 hPa to 1100 hPa).
- **Network Constraints:** Requires a standard 2.4 GHz IEEE 802.11 b/g/n Wi-Fi local access point with Internet connectivity for cloud synchronization.

---

## 1.4. Methodology & Engineering Approach

The project adheres to an iterative hardware-software co-design methodology:
1. **Theoretical Formulation:** Mathematical modeling of optical dust scattering, metal-oxide semiconductor gas reaction kinetics, and battery State-of-Charge (SoC) estimation.
2. **Hardware Design & Prototyping:** Breadboard assembly, verification of electrical signal integrity across SPI and I2C buses, design of the optical sensor RC pulse network, and validation of the 2S battery protection circuit.
3. **Firmware Engineering:** Modular C/C++ development utilizing PlatformIO, implementing non-blocking cooperative scheduling to coordinate sensor sampling, graphical rendering, and network synchronization.
4. **Cloud Infrastructure & Frontend Development:** Configuration of Google Firebase Realtime Database schema and security rules, paired with an asynchronous web dashboard developed using HTML5, CSS3, JavaScript, and Chart.js.
5. **Experimental Validation:** Comprehensive empirical testing including sensor baseline calibration, power consumption profiling across operational states, and battery autonomy benchmarking.

---

## 1.5. Report Organization

The remainder of this report is organized as follows:
- **Chapter 2: Theoretical Background & System Design** details the scientific principles of indoor air quality metrics, sensing transducer technologies, embedded RISC-V architectures, Firebase cloud mechanics, and the overall system design.
- **Chapter 3: Detailed Hardware & Software Design** describes the schematic design, PCB layout, pinout assignments, C/C++ firmware state machines, and web application architecture.
- **Chapter 4: Implementation & Experimental Evaluation** presents the physical assembly, calibration procedures, experimental results, power efficiency benchmarks, and system validation.
- **Chapter 5: Conclusion & Future Work** summarizes the major engineering contributions, discusses system limitations, and outlines future enhancements.

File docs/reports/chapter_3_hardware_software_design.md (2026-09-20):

# Chapter 3: Detailed Hardware & Software Design

## 3.1. Hardware Schematic & Interfacing Design
- **3.1.1. Power Distribution Network:** Integration of 2S Li-ion pack, BMS protection, INA219 shunt sensing, AMS1117-5.0V LDO, and decoupling capacitor placement ($10\mu F$ and $0.1\mu F$ ceramic capacitors).
- **3.1.2. ESP32-C3 Super Mini Pin Allocation:** Detailed hardware pinout mapping, GPIO strapping pin constraints (GPIO2, GPIO8, GPIO9), and pull-up resistor values.
- **3.1.3. Optical Dust Sensor Interface:** Design of the external $150\Omega$ resistor and $220\mu F$ electrolytic capacitor pulse circuit for the Sharp GP2Y1010AU0F.
- **3.1.4. I2C Bus Topology:** Multi-device bus configuration accommodating Bosch BME680 (`0x77`) and INA219 (`0x40`) with 4.7k$\Omega$ bus pull-ups.
- **3.1.5. SPI Display Interface:** 4-wire hardware SPI connection for the 1.8-inch ST7735 TFT LCD.
- **3.1.6. Acoustic Alarm Circuit:** NPN switching transistor driver (2N2222 / SS8050) with base resistor and flyback suppression diode for the TMB09A05 active buzzer.

## 3.2. Embedded Firmware Architecture
- **3.2.1. Modular Firmware Structure:** Overview of PlatformIO project layout, header separation, and driver modularization.
- **3.2.2. Non-Blocking Cooperative Scheduler:** Timer-driven task scheduling using `millis()` for deterministic sensor sampling, display refresh, and cloud transmission without blocking delays.
- **3.2.3. Optical Pulse Timing Routine:** Implementation of microsecond-accurate timing (`delayMicroseconds()`) for the GP2Y1010AU0F IRED excitation.
- **3.2.4. Digital Filtering Algorithms:** Implementation of 10-sample moving average filter (MAF) for analog ADC stabilization.
- **3.2.5. Graphical User Interface Implementation:** Display layout, fonts, color palettes (RGB565), and screen refresh optimization on the ST7735.

## 3.3. Cloud Infrastructure & Web Dashboard
- **3.3.1. Google Firebase Realtime Database Provisioning:** Database structure, node hierarchy, and JSON payload definitions.
- **3.3.2. Security Rules & Token Authentication:** Enforcing read/write access control.
- **3.3.3. Web Application Architecture:** HTML5/CSS3/JavaScript responsive frontend architecture.
- **3.3.4. Real-time Telemetry Visualizer:** Dynamic charting with Chart.js and live gauge indicators.

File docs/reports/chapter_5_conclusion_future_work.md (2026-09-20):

# Chapter 5: Conclusion & Future Work

## 5.1. Summary of Contributions
- Successful development of a low-cost, portable, edge-enabled Indoor Air Quality (IAQ) and Energy Monitoring IoT station powered by the ESP32-C3 Super Mini (RISC-V).
- Accurate multi-parameter environmental sensing integrating fine particulates (PM2.5), volatile organic compounds (VOCs), ambient temperature, relative humidity, and barometric pressure.
- Implementation of an autonomous 2S Li-ion battery subsystem featuring USB Type-C boost charging, 2S BMS protection, and real-time power telemetry via the INA219 sensor.
- Seamless real-time cloud data synchronization with Google Firebase Realtime Database and an intuitive, responsive Web Dashboard for end-user visualization.

## 5.2. Limitations of Current Design
- Optical dust sensing with the Sharp GP2Y1010AU0F is sensitive to ambient air velocity and lacks a laser-driven active fan intake (found in higher-cost laser scattering units like PMS7003).
- Linear voltage regulation (AMS1117-5.0V) exhibits lower efficiency (~67%) compared to synchronous buck switching regulators, generating minor thermal dissipation.
- BME680 VOC reading requires regular baseline adaptation to account for long-term sensor aging.

## 5.3. Recommendations for Future Work
- **Hardware Enhancements:** Upgrade the linear regulator to a high-efficiency buck DC-DC converter (e.g., MP2307 / TPS62160) to boost battery runtime by 25-35%.
- **Sensor Upgrades:** Integrate a laser scattering particulate sensor (e.g., Plantower PMS7003) for precise binning of PM1.0, PM2.5, and PM10.
- **Edge AI & Anomaly Detection:** Implement lightweight TinyML anomaly detection algorithms on the ESP32-C3 to forecast air quality degradation trends locally before cloud upload.
- **Enclosure & Industrial Design:** Fabricate an injection-molded or SLA 3D-printed enclosure with optimized aerodynamic inlet/outlet vents.

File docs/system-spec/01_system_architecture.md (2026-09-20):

# 01. System Architecture Specification

## 1. Overview

The Indoor Air Quality (IAQ) and Energy Monitoring System is engineered as a distributed, edge-enabled IoT platform. It continuously measures indoor microclimate parameters and hazardous airborne pollutants while autonomously managing its own power reserves.

The system is architected in **Three Distinct Tiers**:
1. **Tier 1: Physical Sensing & Edge Node**
2. **Tier 2: Cloud Middleware & Data Synchronization (Google Firebase)**
3. **Tier 3: Client Application & Data Visualization Dashboard**

```
+-----------------------------------------------------------------------------------+
|                           TIER 1: SENSOR & EDGE NODE                              |
|                                                                                   |
|  +--------------------+  +----------------------+  +---------------------------+  |
|  |   Bosch BME680     |  | Sharp GP2Y1010AU0F   |  |     INA219 Power Sense    |  |
|  | (Temp/Hum/Press/Gas|  | (Optical PM2.5 Dust) |  | (2S Battery V, I, Power)  |  |
|  +---------+----------+  +----------+-----------+  +-------------+-------------+  |
|            | I2C                    | Analog ADC/GPIO            | I2C            |
|            +-------------------+    |    +-----------------------+                |
|                                |    |    |                                        |
|                                v    v    v                                        |
|                     +---------------------------+                                 |
|                     | ESP32-C3 Super Mini (MCU) |                                 |
|                     |  - 32-bit RISC-V @ 160MHz |                                 |
|                     |  - Moving Average Filter  |                                 |
|                     |  - Threshold Evaluation   |                                 |
|                     +-------------+-------------+                                 |
|                                   |                                               |
|                  +----------------+----------------+                              |
|                  | SPI                             | GPIO                         |
|                  v                                 v                              |
|     +-------------------------+       +-------------------------+                 |
|     | 1.8" ST7735 TFT Display |       | TMB09A05 Active Buzzer  |                 |
|     | (Real-time Edge UI)     |       | (Acoustic Danger Alarm) |                 |
|     +-------------------------+       +-------------------------+                 |
+-----------------------------------+-----------------------------------------------+
                                    | Wi-Fi 802.11 b/g/n (WSS / HTTPS)
                                    v
+-----------------------------------------------------------------------------------+
|                        TIER 2: GOOGLE FIREBASE CLOUD                              |
|                                                                                   |
|  +-------------------------------------+  +------------------------------------+  |
|  |     Firebase Realtime Database      |  |         Security & Auth            |  |
|  | - /iaq_monitor/{id}/current (Live)  |  | - Database Token / Secret          |  |
|  | - /iaq_monitor/{id}/history (Logs)  |  | - Granular Read/Write Access Rules |  |
|  +-------------------------------------+  +------------------------------------+  |
+-----------------------------------+-----------------------------------------------+
                                    | Real-time Data Stream (WebSockets)
                                    v
+-----------------------------------------------------------------------------------+
|                        TIER 3: USER DASHBOARD & CLIENT                            |
|                                                                                   |
|  +-------------------------------------+  +------------------------------------+  |
|  |       Responsive Web Dashboard      |  |         Alert Notification         |  |
|  | - Real-time Gauge Metrics           |  | - PM2.5 / VOC Spikes               |  |
|  | - Time-series Chart.js Visualizer   |  | - Low Battery State Warning        |  |
|  | - Battery & Power telemetry         |  | - Environmental Quality Index      |  |
|  +-------------------------------------+  +------------------------------------+  |
+-----------------------------------------------------------------------------------+
```

---

## 2. Tier Details

### 2.1. Tier 1: Sensor & Edge Node
- **Core Processor:** ESP32-C3 Super Mini (single-core 32-bit RISC-V processor clocked up to 160 MHz, with 400 KB SRAM and 4MB on-board Flash).
- **Sub-edge Processing:**
  - Performs local sensor data acquisition, digital calibration, and sensor heating cycles (BME680 MOX hotplate).
  - Drives high-precision microsecond pulse modulation for the Sharp GP2Y1010AU0F infrared emitting diode (IRED).
  - Executes moving-average digital filtering on analog ADC readings to eliminate high-frequency noise.
  - Controls an SPI-driven 1.8-inch TFT LCD (ST7735) for real-time visual output.
  - Triggers local acoustic buzzer warnings when air quality drops below predefined health thresholds or battery falls below critical voltage.

### 2.2. Tier 2: Cloud Middleware (Google Firebase)
- **Firebase Realtime Database (RTDB):** Provides low-latency, bi-directional data synchronization over WebSockets and HTTPS.
- **Data Model:**
  - Ephemeral state (`/current`): Stored for immediate dashboard consumption with minimal latency.
  - Persistent state (`/history`): Time-series records logged at regular intervals for historical trend analysis.
- **Security:** Managed via Firebase Realtime Database Security Rules, preventing unauthorized modification.

### 2.3. Tier 3: User Dashboard & Presentation
- **Frontend Technologies:** HTML5, CSS3, JavaScript (ES6+), Chart.js, and Firebase Web SDK.
- **Features:**
  - Real-time gauge dials for PM2.5, VOC Resistance, Temperature, Humidity, and Atmospheric Pressure.
  - Energy telemetry metrics: Battery Voltage, Discharge Current (mA), Power (mW), and Estimated Remaining Battery Percentage.
  - Dynamic alert banners reflecting air quality status (Good, Moderate, Unhealthy, Hazardous).

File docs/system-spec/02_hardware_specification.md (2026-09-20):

# 02. Hardware Specification

## 1. Component Breakdown

This document provides a comprehensive technical breakdown of all physical hardware components utilized in the Indoor Air Quality (IAQ) and Energy Monitoring System.

---

## 2. Microcontroller Unit (MCU): ESP32-C3 Super Mini

- **Architecture:** 32-bit RISC-V Single-Core processor (RV32IMC instruction set).
- **Clock Frequency:** Up to 160 MHz.
- **Memory:** 400 KB SRAM, 384 KB ROM, and 4 MB on-board SPI Flash memory.
- **Wireless Connectivity:**
  - Wi-Fi 802.11 b/g/n (2.4 GHz) with up to 150 Mbps throughput.
  - Bluetooth 5 (LE - Low Energy) and Bluetooth Mesh.
- **Peripherals:** 11 GPIO pins, 4-channel 12-bit ADC (up to 2.5 MHz sampling rate), SPI, I2C, UART, PWM.
- **Form Factor:** Ultra-compact module (22.5 mm x 18 mm) with ceramic antenna and onboard 3.3V LDO regulator.
- **Power Input:** 3.3V (VCC pin) or 5.0V (VIN pin).

---

## 3. Environmental Sensors

### 3.1. Bosch BME680 (4-in-1 Environmental Sensor)
- **Parameters Measured:** Ambient Temperature, Relative Humidity, Barometric Pressure, and Volatile Organic Compounds (VOC) Gas Resistance.
- **Operating Range:**
  - Temperature: -40°C to +85°C (Accuracy: ±1.0°C).
  - Humidity: 0% to 100% RH (Accuracy: ±3% RH).
  - Barometric Pressure: 300 hPa to 1100 hPa (Accuracy: ±0.6 hPa).
  - Gas Sensor: Metal oxide (MOX) sensor sensitive to broad-spectrum volatile organic compounds (VOCs), sulfides, and carbon monoxide.
- **Communication Protocol:** I2C (Default address: `0x77` or `0x76`).
- **Operating Voltage:** 1.71V - 3.6V (Supplied via 3.3V rail).

### 3.2. Sharp GP2Y1010AU0F (Optical Dust Sensor)
- **Target Pollutant:** Suspended particulate matter (PM2.5 / PM10).
- **Operating Principle:** Optical laser/infrared scattering. An infrared emitting diode (IRED) and phototransistor are diagonally arranged inside an air chamber. Scattered light from dust particles generates a proportional analog voltage.
- **Sensitivity:** 0.5V per 100 $\mu g/m^3$.
- **Detection Range:** 0 to 500 $\mu g/m^3$.
- **Operating Voltage:** 4.5V - 5.5V (Supplied via regulated 5.0V rail).
- **Control Signal:** Active-low pulse ($0.32 ms$ duration, period $10 ms$) applied to the I-LED pin.
- **Output:** Analog DC voltage ($V_o$).

---

## 4. Energy Monitoring: INA219 High-Side Power Sensor

- **Function:** Real-time continuous monitoring of 2S battery pack bus voltage, shunt current, and total system power consumption.
- **Shunt Resistor:** 0.1 $\Omega$ (1% precision).
- **Voltage Measurement Range:** 0V to 26V DC (Bus Voltage).
- **Current Measurement Range:** ±3.2A with 0.8mA resolution.
- **ADC Resolution:** 12-bit programmable internal analog-to-digital converter.
- **Communication Protocol:** I2C (Address: `0x40`).
- **Operating Voltage:** 3.0V - 5.5V (Connected to 3.3V logic).

---

## 5. Visual Display: 1.8-inch TFT LCD (ST7735)

- **Display Controller:** Sitronix ST7735.
- **Resolution:** 128 x 160 pixels.
- **Color Depth:** 65K Full RGB (16-bit color, 5-6-5 format).
- **Interface:** 4-wire Serial Peripheral Interface (SPI: SCL, SDA, CS, DC, RES).
- **Backlight:** LED backlight controlled via 3.3V / PWM.
- **Operating Voltage:** 3.3V / 5.0V (Logic pins operating at 3.3V).

---

## 6. Acoustic Indicator: TMB09A05 5V Active Buzzer

- **Type:** Active electromagnetic buzzer with internal oscillation circuit.
- **Dimensions:** 9 mm diameter x 5.5 mm height.
- **Rated Voltage:** 5.0V DC (Operating: 4.0V - 7.0V).
- **Sound Pressure Level (SPL):** $\ge 85 dB$ at 10 cm distance.
- **Resonant Frequency:** 2700 ± 300 Hz.
- **Driving Method:** Switched through an NPN BJT (e.g., 2N2222 / SS8050) driven by an ESP32-C3 GPIO pin.

---

## 7. Power Supply & Battery Subsystem (2S Configuration)

```
[2x 18650 Li-ion Cells in Series (2S1P)]
               |
               v
 [2S 5A BMS Protection Board (Overcharge / Overdischarge)]
               |
        +------+---------------------------------+
        |                                        |
        v                                        v
[Type-C 2S Boost Charger]                [INA219 Power Monitor]
(Charges 2S from 5V Type-C)                      |
                                                 v
                                        [AMS1117-5.0V LDO]
                                                 |
                               +-----------------+-----------------+
                               | 5.0V                              | 5.0V
                               v                                   v
                      [ESP32-C3 VIN pin]                 [Sharp GP2Y1010AU0F & Buzzer]
                               | (Internal 3.3V LDO)
                               v
                      [BME680, ST7735, INA219 Logic]
```

### 7.1. Battery Cells
- **Model:** 18650 Cylindrical Lithium-ion.
- **Configuration:** 2S1P (2 cells in series).
- **Capacity:** 2600 mAh per cell (Total energy: $7.4V \times 2.6Ah \approx 19.24 Wh$).
- **Voltage Range:**
  - Fully Charged: 8.4V (4.2V/cell).
  - Nominal: 7.4V (3.7V/cell).
  - Cutoff / Depleted: 6.0V (3.0V/cell).
- **Enclosure:** 2-slot 18650 battery holder with spring contacts.

### 7.2. Battery Management System (BMS): 2S 5A Protection Board
- **Overcharge Protection Voltage:** 4.25V ± 0.05V per cell.
- **Over-discharge Protection Voltage:** 2.50V ± 0.08V per cell.
- **Continuous Discharge Current:** 5A.
- **Overcurrent Protection Current:** 10A.
- **Protection Features:** Short-circuit recovery, overcharge release, over-discharge cutoff.

### 7.3. Battery Charger: Type-C 3-6V to 2S 2A (8.4V) Boost Charger
- **Input:** 3.0V - 6.0V DC via standard USB Type-C port (compatible with standard 5V mobile chargers and power banks).
- **Output:** 8.4V constant current / constant voltage (CC/CV) charging profile.
- **Charging Current:** 2.0A peak.
- **Indicator LEDs:** Red (Charging), Blue/Green (Charge Complete).

### 7.4. Voltage Regulation: AMS1117-5.0V LDO Module
- **Input Voltage:** 7.4V - 8.4V from the 2S battery pack.
- **Regulated Output Voltage:** 5.0V DC (±1%).
- **Maximum Output Current:** 800 mA - 1.0 A.
- **Dropout Voltage:** ~1.1V at full load.
- **Thermal Management:** Compact PCB heatsink tab.

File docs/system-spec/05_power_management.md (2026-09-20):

# 05. Power Management & Battery Subsystem

## 1. Overview

The Indoor Air Quality (IAQ) monitoring station incorporates an autonomous, portable 2S Lithium-Ion power architecture. The system integrates charging, protection, voltage regulation, and active energy telemetry.

---

## 2. Power Architecture & Component Specifications

```
                       [USB Type-C 5V Input]
                                 |
                                 v
          +----------------------------------------------+
          | Type-C to 2S (8.4V, 2A) Boost Charger Module |
          +----------------------+-----------------------+
                                 |
                                 v
          +----------------------------------------------+
          | 2x 18650 Li-ion Cells (2S1P, 2600mAh, 7.4V)  |
          |       Protected by 2S 5A BMS Board           |
          +----------------------+-----------------------+
                                 | Pack Output (6.0V - 8.4V)
                                 v
          +----------------------------------------------+
          | INA219 High-Side Current & Power Sensor      |
          +----------------------+-----------------------+
                                 |
                                 v
          +----------------------------------------------+
          | AMS1117-5.0V LDO Voltage Regulator           |
          +----------------------+-----------------------+
                                 | Regulated 5.0V Rail
                 +---------------+---------------+
                 |                               |
                 v                               v
        [ESP32-C3 Super Mini]          [Sensors & Peripherals]
         - Onboard 3.3V LDO             - Sharp GP2Y1010AU0F (5V)
         - 3.3V Logic to BME680,        - TMB09A05 Buzzer (5V)
           TFT ST7735, INA219
```

---

## 3. Battery Subsystem Analysis

### 3.1. Cell Characteristics (2S1P)
- **Cell Chemistry:** Lithium Cobalt Oxide / Nickel Manganese Cobalt (Li-ion 18650).
- **Nominal Cell Voltage:** 3.7V per cell ($7.4V$ total for 2S pack).
- **Full Charge Voltage:** 4.2V per cell ($8.4V$ total for 2S pack).
- **Discharge Cut-off Voltage:** 3.0V per cell ($6.0V$ total for 2S pack).
- **Rated Capacity:** 2600 mAh ($2.6 Ah$).
- **Total Energy Storage:**
  $$E_{total} = V_{nominal} \times C = 7.4V \times 2.6Ah \approx 19.24 \, \text{Wh}$$

### 3.2. 2S 5A Battery Management System (BMS)
- **Overcharge Protection:** Disconnects charging if any cell exceeds $4.25V \pm 0.05V$.
- **Over-discharge Protection:** Cuts off output if any cell falls below $2.50V \pm 0.08V$.
- **Overcurrent Cutoff:** Triggers if load exceeds $10A$ peak or $5A$ continuous.
- **Short-circuit Protection:** Instantaneous electronic disconnection with automatic recovery once the fault is cleared.

### 3.3. Type-C 2S Boost Charger
- **Input:** Standard USB Type-C 5V/2A input from any standard wall adapter or power bank.
- **Boost Topology:** Boosts 5V input to 8.4V constant current / constant voltage (CC/CV) algorithm.
- **Charging Current:** 2.0A maximum.
- **Charging Duration:**
  $$T_{charge} \approx \frac{2600 \, \text{mAh}}{2000 \, \text{mA}} \times 1.2 \approx 1.5 - 1.8 \, \text{hours}$$

---

## 4. System Power Budget & Operational Autonomy

| Subsystem / Component | Operating Voltage | Average Current Draw | Peak Current Draw | Average Power |
| :--- | :--- | :--- | :--- | :--- |
| **ESP32-C3 (Active Wi-Fi)** | 3.3V (via internal LDO) | 85 mA | 240 mA (Wi-Fi TX burst) | 280 mW |
| **1.8" TFT LCD (ST7735)** | 3.3V Logic / 5V BL | 30 mA | 45 mA | 150 mW |
| **Bosch BME680** | 3.3V (MOX heater pulsed) | 12 mA | 18 mA (during 150ms heat) | 40 mW |
| **Sharp GP2Y1010AU0F** | 5.0V (0.32ms IRED pulse) | 11 mA | 20 mA (during pulse) | 55 mW |
| **INA219 Sensor** | 3.3V | 1 mA | 1 mA | 3.3 mW |
| **TMB09A05 Buzzer** | 5.0V (Only during alarm) | 0 mA (idle) | 35 mA (alarm state) | 0 mW (nominal) |
| **AMS1117-5.0 Quiescent** | 7.4V - 8.4V | 5 mA | 10 mA | 40 mW |
| **Total Steady-State Load** | **Regulated 5.0V Rail** | **~144 mA** | **~369 mA** | **~568 mW** |

### 4.1. Estimated Continuous Operating Time
Because a linear regulator (AMS1117-5.0V) is used, the input current drawn from the 2S battery pack equals the total load current plus quiescent current:
$$I_{battery} \approx 144 \, \text{mA} + 5 \, \text{mA} \approx 149 \, \text{mA} \approx 150 \, \text{mA}$$

Assuming an $85\%$ usable battery discharge window before reaching the cutoff threshold:
$$T_{run} = \frac{2600 \, \text{mAh} \times 0.85}{150 \, \text{mA}} \approx 14.7 \, \text{hours of continuous active operation}$$

### 4.2. Power Optimization Strategies
1. **Dynamic Wi-Fi Sleep:** Switching the ESP32-C3 Wi-Fi subsystem into Modem-Sleep mode between 5-second cloud sync intervals reduces the average MCU current from 85 mA to under 25 mA.
2. **Display Timeout:** Dimming the ST7735 backlight after 60 seconds of inactivity saves an additional 25 mA.
3. **With Power Optimizations:** Total average current drops to $\approx 65 \, \text{mA}$, extending battery autonomy to over **34 hours**.

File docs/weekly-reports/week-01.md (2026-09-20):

# Weekly Progress Report: Week 01

**Reporting Period:** 2026-09-01 to 2026-09-07  
**Project Name:** Indoor Air Quality (IAQ) & Energy Monitoring IoT System  
**Phase:** Phase 1: Inception & Technical Specification  

---

## 1. Executive Summary
Week 01 focused on project inception, problem formulation, and establishing theoretical foundations. Comprehensive research was conducted on indoor airborne contaminants (PM2.5, VOCs, CO2) and international air quality standards (WHO, US-EPA). The project scope, engineering requirements, and **Chapter 1: Introduction** were authored and finalized.

---

## 2. Objectives for the Week
- [x] **Objective 1:** Define the core problem statement, research motivation, and target scope for an indoor environmental monitoring station.
- [x] **Objective 2:** Conduct a comprehensive literature survey on indoor air contaminants and health implications.
- [x] **Objective 3:** Author and finalize **Chapter 1: Introduction** of the project report.
- [x] **Objective 4:** Establish the initial project repository structure and documentation standards.

---

## 3. Accomplishments & Key Deliverables

### 3.1. Problem Formulation & Scope Definition
- Analyzed indoor environmental data indicating that humans spend over 85% of their daily time indoors, where pollutant concentrations can exceed outdoor levels by 2 to 5 times.
- Identified target pollutants for the monitoring station: Fine Particulate Matter ($PM_{2.5}$), Volatile Organic Compounds (VOCs), ambient Temperature, Relative Humidity, and Barometric Pressure.
- Established the need for self-contained, portable power management with real-time energy telemetry.

### 3.2. Technical Documentation
- Authored **[Chapter 1: Introduction](../reports/chapter_1_introduction.md)** covering:
  - Background & Problem Statement.
  - Research Objectives & Targeted Capabilities.
  - Scope & Delimitations.
  - Scientific and Practical Significance.
  - Overall Report Organization.
- Established the project directory layout and version control conventions on GitHub.

---

## 4. Key Metrics & Deliverables Table

| Deliverable | Target Deadline | Actual Completion | Status |
| :--- | :--- | :--- | :---: |
| Project Charter & Requirements | 2026-09-03 | 2026-09-03 | PASS |
| Literature Review on IAQ & PM2.5 | 2026-09-05 | 2026-09-05 | PASS |
| Chapter 1: Introduction Draft | 2026-09-07 | 2026-09-07 | PASS |

---

## 5. Challenges, Impediments & Mitigations

| Challenge / Issue | Root Cause | Impact | Mitigation / Solution |
| :--- | :--- | :--- | :--- |
| Narrowing target pollutants | Broad variety of indoor gases (CO, CO2, Formaldehyde, Ozone, VOCs) | Medium | Selected the Bosch BME680 sensor which provides multi-gas / VOC resistance alongside full climate parameters, paired with a dedicated optical PM2.5 sensor. |
| Power supply constraints | Continuous Wi-Fi and sensor heating demands significant power | High | Decided to adopt a 2S Li-ion battery pack with autonomous BMS and INA219 energy monitoring to evaluate battery lifetime accurately. |

---

## 6. Objectives for Next Week (Week 02)
- [ ] **Objective 1:** Select exact physical components (MCU, sensors, display, battery subsystem).
- [ ] **Objective 2:** Design the 3-tier system architecture and pinout allocation.
- [ ] **Objective 3:** Author and complete **Chapter 2: Theoretical Background & System Design**.
- [ ] **Objective 4:** Compile technical specifications in `docs/system-spec/`.

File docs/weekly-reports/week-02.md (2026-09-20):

# Weekly Progress Report: Week 02

**Reporting Period:** 2026-09-08 to 2026-09-14  
**Project Name:** Indoor Air Quality (IAQ) & Energy Monitoring IoT System  
**Phase:** Phase 1: Inception & Technical Specification  

---

## 1. Executive Summary
Week 02 successfully finalized all hardware selections and system architecture design. The core processor was designated as the ESP32-C3 Super Mini (RISC-V architecture), paired with the Bosch BME680, Sharp GP2Y1010AU0F optical dust sensor, and INA219 power telemetry module. A rechargeable 2S Li-ion battery management subsystem was architected with USB Type-C charging and AMS1117-5.0V regulation. Technical specifications (`docs/system-spec/01` through `05`) and **Chapter 2: Theoretical Background & System Design** were authored and completed.

---

## 2. Objectives for the Week
- [x] **Objective 1:** Finalize hardware component selection and compile the complete Bill of Materials (BOM).
- [x] **Objective 2:** Design the 3-Tier IoT System Architecture (Edge Node, Firebase Cloud, Web Dashboard).
- [x] **Objective 3:** Author **Chapter 2: Theoretical Background & System Design**.
- [x] **Objective 4:** Author detailed technical specifications for system architecture, hardware, pinout, software, and power management.

---

## 3. Accomplishments & Key Deliverables

### 3.1. Hardware Component Selection & BOM
- Selected **ESP32-C3 Super Mini** (32-bit RISC-V @ 160MHz, 4MB Flash) for its ultra-compact form factor, built-in Wi-Fi/BLE, and low power consumption.
- Selected **Bosch BME680** for 4-in-1 climate and VOC gas sensing via I2C.
- Selected **Sharp GP2Y1010AU0F** for optical infrared PM2.5 dust detection.
- Selected **INA219** for high-side current and voltage sensing on the 2S battery bus.
- Selected **1.8" ST7735 TFT LCD** (SPI) for on-device graphical visual feedback.
- Designed **2S Li-ion Power Subsystem:**
  - 2x 18650 2600mAh cells (7.4V nominal, 8.4V full).
  - 2S 5A BMS protection board.
  - Type-C 3-6V to 2S 2A boost charger module.
  - AMS1117-5.0V LDO regulator.
  - TMB09A05 5V active buzzer.

### 3.2. Technical Documentation
- Authored **[Chapter 2: Theoretical Background & System Design](../reports/chapter_2_theoretical_background.md)**:
  - IAQ metrics, health standards (WHO, US-EPA), and particulate classification.
  - Optical dust detection principles ($0.32ms$ pulse timing and ADC transfer curve).
  - Metal oxide (MOX) gas sensing principles and VOC resistance behavior.
  - Shunt resistor current measurement theory and I2C telemetry via INA219.
  - Google Firebase Realtime Database architecture and synchronization mechanisms.
- Produced technical specifications:
  - `docs/system-spec/01_system_architecture.md`
  - `docs/system-spec/02_hardware_specification.md`
  - `docs/system-spec/03_circuit_and_pinout.md`
  - `docs/system-spec/04_software_and_cloud_spec.md`
  - `docs/system-spec/05_power_management.md`

---

## 4. Key Metrics & Deliverables Table

| Deliverable | Target Deadline | Actual Completion | Status |
| :--- | :--- | :--- | :---: |
| Complete Bill of Materials (BOM) | 2026-09-10 | 2026-09-10 | PASS |
| System Specification Documents (01-05) | 2026-09-12 | 2026-09-12 | PASS |
| Chapter 2: Theoretical Background | 2026-09-14 | 2026-09-14 | PASS |

---

## 5. Challenges, Impediments & Mitigations

| Challenge / Issue | Root Cause | Impact | Mitigation / Solution |
| :--- | :--- | :--- | :--- |
| Limited GPIO on ESP32-C3 | ESP32-C3 Super Mini breaks out only 11 GPIO pins | High | Carefully allocated buses: shared I2C bus (SDA: GPIO8, SCL: GPIO9) for BME680 and INA219; dedicated hardware SPI pins for ST7735; remaining GPIO for dust pulse (GPIO1), ADC (GPIO0), and buzzer (GPIO2). |
| 5V requirement for GP2Y1010AU0F & Buzzer | ESP32-C3 operates at 3.3V logic | Medium | Added AMS1117-5.0V to step down 2S battery pack (7.4V-8.4V) to stable 5.0V. Used NPN transistor for buzzer driving and confirmed GP2Y1010AU0F analog output stays within ESP32-C3 ADC limits. |

---

## 6. Objectives for Next Week (Week 03)
- [ ] **Objective 1:** Procure physical components and test individual modules on breadboard.
- [ ] **Objective 2:** Construct and verify the Sharp GP2Y1010AU0F RC pulse driving circuit ($150\Omega$, $220\mu F$).
- [ ] **Objective 3:** Validate 2S BMS protection board cutoff and Type-C boost charger.
- [ ] **Objective 4:** Develop preliminary sensor acquisition drivers in PlatformIO C/C++.

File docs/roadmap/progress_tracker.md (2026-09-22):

# Project Progress Tracker & Checklist

## 1. Overall Progress Summary

| Week / Milestone | Core Engineering Objectives | Status | Progress |
| :--- | :--- | :---: | :---: |
| **Week 1** | Inception, IAQ Standards & Chapter 1 Report | **Completed** | 100% |
| **Week 2** | System Architecture, Tech Specs & Chapter 2 Report | **Completed** | 100% |
| **Weeks 3 – 4** | Component Sourcing & Breadboard Peripheral Testing | **Completed** | 100% |
| **Week 5** | Full Breadboard Integration & Web Dashboard Layout | **Completed** | 100% |
| **Week 6** *(Current)* | KiCad Schematic Capture & PCB Fabrication Prep | **In Progress** | 80% |
| **Week 7** | PCB Assembly, Hardware Bring-Up & Cloud Setup | **Pending** | 0% |
| **Week 8** | Firebase Realtime Sync, Acoustic Alerting & 3D Box | **Pending** | 0% |
| **Week 9** | 24h Stability, Final Documentation & Project Defense | **Pending** | 0% |

---

## 2. Detailed Task Checklist

### Week 1: Project Inception & Requirements Analysis
- [x] Define project scope, target indoor air quality parameters, and problem statement.
- [x] Research WHO and US-EPA IAQ standards (PM2.5 limits, VOC exposure, thermal comfort).
- [x] Select core hardware components (ESP32-C3 Super Mini, BME680, GP2Y1010AU0F, INA219, ST7735).
- [x] Author and finalize **Chapter 1: Introduction**.

### Week 2: System Architecture & Technical Specifications
- [x] Formulate 3-Tier IoT System Architecture (Sensor Node -> Google Firebase -> Web Dashboard).
- [x] Design 2S Li-ion battery power subsystem (18650 cells, 2S 5A BMS, Type-C boost charger, AMS1117-5.0V).
- [x] Author and finalize **Chapter 2: Theoretical Background & System Design**.
- [x] Compile Technical System Specifications (`docs/system-spec/01` to `05`).
- [x] Establish GitHub repository structure and version control workflow.

### Weeks 3 – 4: Hardware Procurement & Breadboard Subsystem Testing
- [x] Procure all physical Bill of Materials (BOM) components.
- [x] Verify ESP32-C3 Super Mini GPIO breakout pinout and power rails on breadboard.
- [x] Assemble and validate Sharp GP2Y1010AU0F RC pulse driver circuit (150 ohm resistor, 220 uF capacitor) on breadboard.
- [x] Wire I2C bus with BME680 and INA219 using pull-up resistors and verify basic address communication.
- [x] Test 2S 18650 battery holder, BMS protection board, and AMS1117-5.0V output voltage stability.

### Week 5: Full Breadboard Integration & Web App Frontend
- [x] Interconnect all modules on breadboard (ESP32-C3, sensors, 1.8" ST7735 TFT, power rails).
- [x] Flash initial firmware to test local screen rendering and sensor data acquisition.
- [x] Develop responsive Web Dashboard layout (`src/frontend/index.html`, `app.js`, CSS) using Chart.js for data visualization.
- [x] Define Firebase Realtime Database payload schema and draft configuration file (`firebase_config.h`).

### Week 6: KiCad Schematic Capture & PCB Preparation (Current Week)
- [x] Author full electronic circuit schematic in KiCad (`hardware/schematics/1.kicad_sch`, `circuit_schematic.png`).
- [x] Assign footprints and verify design rules (ERC) based on the breadboard prototype.
- [x] Lay out PCB traces and prepare Gerber/manufacturing files.
- [ ] Etch/order raw PCB (board trắng) and inspect traces for continuity and short-circuits.

### Week 7: PCB Soldering, Hardware Bring-Up & Cloud Configuration
- [ ] Solder power components (2S BMS, AMS1117-5.0V), ESP32-C3 Super Mini, and passive filters onto PCB.
- [ ] Mount external sensors (BME680, INA219, GP2Y1010AU0F) and ST7735 display onto the board.
- [ ] Measure voltage rails to verify stable operation under battery load.
- [ ] Flash bring-up firmware to validate PCB pinouts, I2C bus addressing, and SPI screen.
- [ ] Configure Google Firebase project, Realtime Database (RTDB), and security access rules.

### Week 8: Firebase Realtime Sync, Acoustic Alerting & 3D Packaging
- [ ] Connect ESP32-C3 to local Wi-Fi and push JSON telemetry to Firebase RTDB every 5 seconds.
- [ ] Connect Web Dashboard to Firebase via WebSocket for live graph updates.
- [ ] Assemble NPN transistor circuit for 5V active buzzer and implement threshold alarm logic (PM2.5/VOC/Battery).
- [ ] 3D print enclosure body and faceplate with airflow channels for sensors.
- [ ] Fit assembled board, battery pack, and display securely inside the enclosure.

### Week 9: Verification, Final Academic Report & Project Defense
- [ ] Run continuous 24-hour stability bench test without disconnection or memory leaks.
- [ ] Measure operating current draw across active Wi-Fi states and evaluate battery autonomy.
- [ ] Complete **Chapter 3: Detailed Hardware & Software Design**.
- [ ] Complete **Chapter 4: Implementation, Testing & Experimental Evaluation**.
- [ ] Complete **Chapter 5: Conclusion & Future Work**.
- [ ] Conduct final codebase audit, prepare presentation slide deck, record product video demo, and deliver project defense.

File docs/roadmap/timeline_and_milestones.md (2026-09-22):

# Project Roadmap: Weekly Milestones

## Phase 1: Inception & Technical Specification (Weeks 1–2)

### Week 1: Problem Formulation & Requirements Analysis

* Define the project scope for indoor air quality monitoring.
* Identify monitored parameters:

  * PM2.5
  * Temperature
  * Humidity
  * Gas/VOC indicators
  * Battery status
* Review relevant air-quality guidelines and monitoring requirements.
* Define the initial hardware Bill of Materials (BOM).
* Complete **Chapter 1: Introduction**.

### Week 2: System Architecture & Technical Specifications

* Define the 3-Tier IoT architecture:
  **Sensor Node → Firebase → Web Dashboard**.
* Select the main hardware:

  * ESP32-C3 Super Mini
  * BME680
  * GP2Y1010AU0F
  * INA219
  * ST7735 TFT
* Design the battery and power subsystem.
* Define communication interfaces and GPIO assignments.
* Prepare the technical system specifications.
* Complete **Chapter 2: Theoretical Background & System Design**.

## Phase 2: Breadboard Prototyping & Circuit Design (Weeks 3–5)

### Week 3: Breadboard Prototype

* Assemble the main components on a breadboard.
* Verify power distribution and voltage levels.
* Connect and test the ESP32-C3, BME680, GP2Y1010AU0F, INA219, and ST7735 TFT.
* Test basic sensor communication.
* Verify sensor readings and display output.
* Identify and correct initial hardware connection problems.

### Week 4: Local Firmware Development

* Develop the initial ESP32-C3 firmware.
* Implement sensor data acquisition.
* Display temperature, humidity, PM2.5, gas information, and battery status on the TFT.
* Implement basic buzzer/alarm functionality.
* Test the firmware using the breadboard prototype.
* Verify stable operation of the main hardware modules.

### Week 5: KiCad Schematic Development

* Transfer the verified breadboard circuit into KiCad.
* Create the complete electrical schematic.
* Define component symbols, power rails, GPIO connections, sensor interfaces, display interface, and battery monitoring circuit.
* Perform Electrical Rules Check (ERC).
* Compare the KiCad schematic with the working breadboard circuit.
* Prepare the schematic for PCB layout.

## Phase 3: PCB Development & Hardware Finalization (Week 6)

### Week 6: PCB Layout & Hardware Preparation — Current Week

* Complete and verify the KiCad schematic.
* Import the schematic into KiCad PCB Editor.
* Assign and verify component footprints.
* Define PCB board dimensions and mounting holes.
* Arrange components according to functional and mechanical requirements.
* Route power and signal traces.
* Pay particular attention to:

  * Power distribution
  * Sensor signal integrity
  * ESP32-C3 antenna clearance
  * Ground connections
  * Display and sensor interfaces
* Run Design Rules Check (DRC).
* Generate Gerber files for PCB fabrication.
* Prepare the PCB for manufacturing.

**Current Progress:**

* KiCad schematic: **Completed**
* Breadboard prototype: **Completed and tested**
* PCB design: **In progress**
* PCB fabrication: **Not yet completed**

## Phase 4: Cloud Integration & System Testing (Weeks 7–8)

### Week 7: Wi-Fi, Firebase & Web Dashboard Integration

* Implement Wi-Fi connectivity on the ESP32-C3.
* Connect the ESP32-C3 to Firebase Realtime Database.
* Implement periodic sensor telemetry transmission.
* Send temperature, humidity, PM2.5, gas/VOC, battery voltage, and battery current data.
* Develop and test the Web Dashboard.
* Display real-time sensor data using charts.
* Implement automatic Wi-Fi reconnection.
* Verify the complete communication chain:
  **Sensor → ESP32-C3 → Wi-Fi → Firebase → Web Dashboard**.

### Week 8: System Testing, Calibration & Power Evaluation

* Assemble and test the fabricated PCB.
* Compare PCB operation with the original breadboard prototype.
* Perform sensor calibration.
* Configure PM2.5 and low-battery alarm thresholds.
* Test buzzer warning and critical alarm patterns.
* Measure active and idle current consumption using INA219.
* Conduct a long-duration stability test.
* Evaluate battery operating time under different Wi-Fi transmission intervals.

## Phase 5: Packaging, Field Evaluation & Final Defense (Week 9)

### Week 9: Enclosure, Field Testing & Final Defense

**Hardware & Packaging**

* Design and fabricate the protective enclosure.
* Install the PCB, ESP32-C3, sensors, TFT display, and battery pack.
* Verify appropriate airflow around the environmental sensors.
* Perform final electrical and mechanical inspection.

**Experimental Evaluation**

* Deploy the system in different indoor environments:

  * Office
  * Kitchen
  * Laboratory
* Record sensor responses to cooking fumes, dust disturbance, and ventilation changes.
* Evaluate system stability and communication reliability.
* Record battery discharge behavior.
* Compare experimental results with theoretical expectations.

**Final Documentation**

* Complete **Chapter 3: Detailed Hardware & Software Design**.
* Complete **Chapter 4: Implementation, Testing & Experimental Evaluation**.
* Complete **Chapter 5: Conclusion & Future Work**.
* Perform final code and hardware audit.
* Organize project files and documentation.

**Defense Preparation**

* Prepare presentation slides.
* Prepare system block diagrams and circuit diagrams.
* Prepare experimental results and graphs.
* Record the end-to-end demonstration:
  **Sensors → ESP32-C3 → Firebase → Web Dashboard**.
* Complete final submission and defense preparation.

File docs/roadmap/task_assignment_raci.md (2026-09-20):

# Task Assignment & RACI Matrix

## 1. Work Breakdown Structure (WBS)

The development tasks are divided across five functional domains:

```
Indoor Air Quality IoT Project
├── 1.0 Hardware & Circuit Engineering
│   ├── 1.1 Schematic design & pinout allocation
│   ├── 1.2 2S Li-ion battery pack, BMS & Type-C boost charger integration
│   ├── 1.3 Sharp GP2Y1010AU0F pulse & filter circuit assembly
│   ├── 1.4 Sensor bus wiring (I2C: BME680, INA219; SPI: ST7735)
│   └── 1.5 Transistor driver circuit for TMB09A05 buzzer
├── 2.0 Embedded Firmware Development
│   ├── 2.1 Microcontroller initialization (ESP32-C3 RISC-V, PlatformIO)
│   ├── 2.2 Microsecond pulse timing & ADC sampling for PM2.5 dust sensor
│   ├── 2.3 I2C driver integration (Bosch BME680 & INA219 energy monitor)
│   ├── 2.4 SPI driver & graphical rendering on ST7735 1.8" TFT
│   └── 2.5 Non-blocking cooperative scheduler & power optimization
├── 3.0 Cloud & Middleware Infrastructure
│   ├── 3.1 Google Firebase project setup & Realtime Database provisioning
│   ├── 3.2 Firebase security rules & authentication token configuration
│   └── 3.3 Data schema design for live telemetry and historical logging
├── 4.0 Frontend & Visualization Dashboard
│   ├── 4.1 Responsive web interface (HTML5/CSS3)
│   ├── 4.2 Firebase JavaScript SDK integration (real-time data streaming)
│   ├── 4.3 Time-series chart visualization (Chart.js)
│   └── 4.4 Environmental alert banners and battery health indicators
└── 5.0 Verification & Technical Documentation
    ├── 5.1 Weekly progress reporting & milestone verification
    ├── 5.2 Technical specification documentation
    └── 5.3 Academic engineering project report (Chapters 1 to 5)
```

---

## 2. RACI Matrix

The RACI matrix defines role responsibilities:
- **R - Responsible:** The role that performs the activity to achieve the deliverable.
- **A - Accountable:** The sole role with final approval and ownership of the deliverable.
- **C - Consulted:** A subject matter expert whose input is sought during execution.
- **I - Informed:** An individual kept updated on progress and results.

### Role Definitions:
- **PM / Arch:** Project Lead & System Architect
- **HW:** Hardware & Circuit Engineer
- **FW:** Embedded Firmware Engineer
- **Cloud/Web:** Cloud & Web Frontend Developer
- **Doc:** Documentation & Verification Specialist

| WBS Code | Deliverable / Task Description | PM / Arch | HW | FW | Cloud/Web | Doc |
| :--- | :--- | :---: | :---: | :---: | :---: | :---: |
| **1.1** | Pinout Allocation & Bus Topology | **A** | **R** | **C** | I | I |
| **1.2** | 2S Battery, BMS & Type-C Charger Integration | A | **R** | C | I | I |
| **1.3** | Sharp GP2Y1010AU0F Pulse Circuit Assembly | A | **R** | **R** | I | I |
| **1.4** | Sensor Bus Wiring (I2C & SPI) | A | **R** | C | I | I |
| **1.5** | Buzzer Driving Circuit & Audio Testing | A | **R** | C | I | I |
| **2.1** | ESP32-C3 PlatformIO Environment Setup | A | C | **R** | I | I |
| **2.2** | Sharp GP2Y1010AU0F Timing & Moving Average Filter | A | C | **R** | I | I |
| **2.3** | BME680 & INA219 I2C Drivers Implementation | A | I | **R** | I | I |
| **2.4** | ST7735 Graphical Dashboard UI Rendering | A | I | **R** | C | I |
| **2.5** | Power-Save Logic (Modem-Sleep & Display Dimming)| A | C | **R** | I | I |
| **3.1** | Firebase Realtime Database Provisioning | A | I | C | **R** | I |
| **3.2** | Firebase Security Rules & Authentication | **A** | I | C | **R** | I |
| **3.3** | JSON Payload Schema Definition | **A** | I | **R** | **R** | I |
| **4.1** | Web Dashboard UI Layout & Design | A | I | I | **R** | I |
| **4.2** | Firebase SDK WebSocket Data Stream | A | I | C | **R** | I |
| **4.3** | Chart.js Time-Series Telemetry Graphs | A | I | I | **R** | I |
| **4.4** | Threshold Alarms & Visual Indicators | A | I | C | **R** | I |
| **5.1** | Weekly Progress Reports (Weeks 1 to 12) | **A** | C | C | C | **R** |
| **5.2** | Technical Specifications (Docs 01 to 05) | **A** | **R** | **R** | **R** | **R** |
| **5.3** | Academic Engineering Report (Chapters 1 to 5) | **A** | C | C | C | **R** |

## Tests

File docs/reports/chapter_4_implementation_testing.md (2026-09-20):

# Chapter 4: Implementation & Experimental Evaluation

## 4.1. Physical Prototype Assembly & Construction
- **4.1.1. Breadboard & PCB Prototyping:** Step-by-step assembly of the sensor node and power subsystem.
- **4.1.2. Wiring Harness & Enclosure Integration:** Arrangement of 18650 battery holder, display bezel, and airflow channels for particulate ingress.

## 4.2. Sensor Calibration & Validation Procedures
- **4.2.1. Sharp GP2Y1010AU0F Baseline Zero-Dust Calibration:** Measuring zero-dust offset voltage $V_{clean}$ in a sealed HEPA chamber and evaluating transfer slope.
- **4.2.2. BME680 MOX Gas Sensor Burn-In:** 48-hour continuous burn-in procedure to stabilize baseline gas resistance ($R_{base}$).
- **4.2.3. Microclimate Sensor Cross-Verification:** Comparing temperature and humidity readings against calibrated reference hygrometers.

## 4.3. Experimental Results & Performance Analysis
- **4.3.1. Transient Pollution Response Testing:** Evaluating system response to indoor cooking smoke, incense combustion, and ethanol vapor exposure.
- **4.3.2. Optical Dust Sensor Response Time:** Measurement of detection latency and moving average filter smoothing performance.
- **4.3.3. Acoustic Alarm & Threshold Triggering:** Verification of active buzzer activation under hazardous PM2.5 and low battery voltage events.

## 4.4. Power Consumption & Battery Autonomy Profiling
- **4.4.1. Telemetry Data Logging with INA219:** Current draw profiles during active Wi-Fi transmission, display refresh, and idle states.
- **4.4.2. Battery Discharge Curve Validation:** Continuous runtime test of the 2S 2600mAh battery pack from 8.4V full charge to 6.0V cutoff.
- **4.4.3. Evaluation of Power-Saving Strategies:** Comparison of continuous active mode versus modem-sleep duty cycling.

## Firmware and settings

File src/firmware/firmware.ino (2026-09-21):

#include <Adafruit_GFX.h>    
#include <Adafruit_ST7735.h> 
#include <SPI.h>
#include <Wire.h>
#include <Adafruit_Sensor.h>
#include <Adafruit_BME680.h>
#include <Adafruit_INA219.h>

// File cấu hình thông tin Wi-Fi và Google Firebase Realtime Database
#include "firebase_config.h"

// ==========================================
// 1. CẤU HÌNH CHÂN MÀN HÌNH TFT (ST7735 1.8")
// ==========================================
#define TFT_CS   21  
#define TFT_DC   20  
#define TFT_RST  10  
#define TFT_MOSI 9   
#define TFT_SCLK 8   
#define TFT_BL   5   

Adafruit_ST7735 tft = Adafruit_ST7735(TFT_CS, TFT_DC, TFT_MOSI, TFT_SCLK, TFT_RST);

// ==========================================
// 2. CẤU HÌNH I2C (BME680 & INA219)
// ==========================================
#define I2C_SDA  6
#define I2C_SCL  7

Adafruit_BME680 bme; 
Adafruit_INA219 ina219;

// ==========================================
// 3. CẤU HÌNH CẢM BIẾN BỤI PM2.5 & CÒI BÍP
// ==========================================
#define DUST_LED_PIN  3  
#define DUST_VO_PIN   4  
#define BUZZER_PIN    2  

// ==========================================
// 4. MÀU SẮC GIAO DIỆN (RGB565)
// ==========================================
#define COLOR_BG      0x0000 
#define COLOR_PANEL   0x18E3 
#define COLOR_TEXT    0xFFFF 
#define COLOR_ACCENT  0x03EF 
#define COLOR_WARN    0xF800 

// ==========================================
// PROTOTYPES CÁC HÀM VẼ GIAO DIỆN
// ==========================================
void drawSplashScreen();
void drawDashboardLayout();
void updateSensorData(float temp, float humi, float dust, float gas, float batVolt, float current_mA, float batPct);

void setup() {
  Serial.begin(115200);
  delay(500);

  Wire.begin(I2C_SDA, I2C_SCL);

  pinMode(DUST_LED_PIN, OUTPUT);
  digitalWrite(DUST_LED_PIN, HIGH);
  analogSetAttenuation(ADC_11db);

  pinMode(BUZZER_PIN, OUTPUT);
  digitalWrite(BUZZER_PIN, LOW); 

  pinMode(TFT_BL, OUTPUT);
  digitalWrite(TFT_BL, HIGH);

  tft.initR(INITR_BLACKTAB);
  tft.setRotation(1); // Màn hình nằm ngang
  tft.fillScreen(COLOR_BG);

  drawSplashScreen();

  if (!bme.begin()) {
    tft.fillScreen(COLOR_BG);
    tft.setCursor(10, 50); tft.setTextColor(ST7735_RED);
    tft.println("Loi: Khong thay BME680!");
    Serial.println(F("[ERROR] Khong tim thay BME680!"));
    while (1);
  }
  bme.setTemperatureOversampling(BME680_OS_8X);
  bme.setHumidityOversampling(BME680_OS_2X);
  bme.setPressureOversampling(BME680_OS_4X);
  bme.setIIRFilterSize(BME680_FILTER_SIZE_3);
  bme.setGasHeater(320, 150);

  if (!ina219.begin()) {
    tft.fillScreen(COLOR_BG);
    tft.setCursor(10, 50); tft.setTextColor(ST7735_RED);
    tft.println("Loi: Khong thay INA219!");
    Serial.println(F("[ERROR] Khong tim thay INA219!"));
    while (1);
  }

  // Âm thanh khởi động (bíp 2 tiếng)
  digitalWrite(BUZZER_PIN, HIGH); delay(100);
  digitalWrite(BUZZER_PIN, LOW);  delay(100);
  digitalWrite(BUZZER_PIN, HIGH); delay(100);
  digitalWrite(BUZZER_PIN, LOW);

  drawDashboardLayout();

  Serial.println(F("[SYSTEM] Khoi tao he thong hoan tat!"));
}

void loop() {
  // 1. Đọc BME680 (Nhiệt độ, Độ ẩm, Khí Gas VOC)
  float temp = 0, humi = 0, gas = 0;
  if (bme.performReading()) {
    temp = bme.temperature;
    humi = bme.humidity;
    gas = bme.gas_resistance ? bme.gas_resistance / 1000.0 : 0;
  }

  // 2. Đọc Bụi PM2.5 Sharp GP2Y1010AU0F (Bộ lọc trung bình 5 mẫu)
  float sumVoltage = 0;
  int sampleCount = 5;
  for (int i = 0; i < sampleCount; i++) {
    digitalWrite(DUST_LED_PIN, LOW);  
    delayMicroseconds(280);           
    int rawValue = analogRead(DUST_VO_PIN); 
    delayMicroseconds(40);            
    digitalWrite(DUST_LED_PIN, HIGH); 
    delayMicroseconds(9680);          
    sumVoltage += (rawValue * 3.3 / 4095.0) * 1.5; 
    delay(5);
  }
  float avgVoltage = sumVoltage / sampleCount;
  float dustDensity = (0.17 * avgVoltage - 0.1);
  if (dustDensity < 0) dustDensity = 0.0;

  // 3. Đọc thông số Nguồn từ INA219 (Điện áp, Dòng điện)
  float busvoltage = ina219.getBusVoltage_V(); 
  float current_mA = ina219.getCurrent_mA();   // Dòng điện tiêu thụ (mA)
  
  // Tính % dung lượng pin 2S (Dải đo 2S: 6.0V đến 8.4V)
  float batteryPct = (busvoltage - 6.0) / (8.4 - 6.0) * 100.0;
  if (batteryPct > 100) batteryPct = 100;
  if (batteryPct < 0) batteryPct = 0;

  // 4. Kiểm tra điều kiện cảnh báo còi bíp (Bụi cao hoặc Pin yếu)
  if (dustDensity > 0.15 || batteryPct < 20.0) {
    digitalWrite(BUZZER_PIN, HIGH);
    delay(200); 
    digitalWrite(BUZZER_PIN, LOW);
  }

  // 5. Cập nhật dữ liệu lên màn hình ST7735
  updateSensorData(temp, humi, dustDensity, gas, busvoltage, current_mA, batteryPct);

  // Ghi log qua cổng Serial
  Serial.printf("[SENSOR] Temp: %.1f C | Humi: %.1f %% | PM2.5: %.3f mg/m3 | Gas: %.1f kOhm | Bat: %.2fV (%.0f%%) %.0fmA\n",
                temp, humi, dustDensity, gas, busvoltage, batteryPct, current_mA);

  // =========================================================================
  // GHI CHÚ CHO PHẦN ĐẨY DỮ LIỆU LÊN GOOGLE FIREBASE (SỬA TRỰC TIẾP TẠI ĐÂY):
  // Khi cần upload lên Firebase:
  // 1. Thêm #include <WiFi.h> và #include <Firebase_ESP_Client.h> ở đầu file.
  // 2. Kết nối WiFi bằng WIFI_SSID và WIFI_PASSWORD trong "firebase_config.h".
  // 3. Khởi tạo Firebase với FIREBASE_HOST và FIREBASE_AUTH.
  // 4. Gọi Firebase.RTDB.setJSON(...) hoặc setFloat(...) đẩy dữ liệu vào node /iaq_stations/ESP32C3_STATION_01/current.
  // =========================================================================

  delay(2000); 
}

// ==========================================
// CÁC HÀM VẼ GIAO DIỆN MÀN HÌNH ST7735
// ==========================================

void drawSplashScreen() {
  tft.fillScreen(COLOR_BG);
  tft.drawRect(5, 5, tft.width() - 10, tft.height() - 10, COLOR_ACCENT);
  tft.setTextSize(1); tft.setTextColor(ST7735_YELLOW);
  tft.setCursor(20, 30); tft.println("DANH GIA CHAT LUONG");
  tft.setCursor(45, 45); tft.println("KHONG KHI");
  tft.setTextColor(ST7735_CYAN);
  tft.setCursor(35, 75); tft.println("System Starting...");
  delay(1500);
}

void drawDashboardLayout() {
  tft.fillScreen(COLOR_BG);

  // Thanh tiêu đề đề tài
  tft.fillRect(0, 0, tft.width(), 16, COLOR_ACCENT);
  tft.setTextSize(1); tft.setTextColor(ST7735_WHITE);
  tft.setCursor(12, 4); tft.println("DG CHAT LUONG KHONG KHI");

  // Khung 4 ô cảm biến môi trường
  tft.drawRoundRect(2, 18, 76, 42, 4, COLOR_PANEL); // Temp
  tft.drawRoundRect(82, 18, 76, 42, 4, COLOR_PANEL); // Humi
  tft.drawRoundRect(2, 62, 76, 42, 4, COLOR_PANEL); // PM2.5
  tft.drawRoundRect(82, 62, 76, 42, 4, COLOR_PANEL); // Gas

  // Khung thanh trạng thái nguồn điện ở đáy
  tft.drawRoundRect(2, 106, tft.width() - 4, 20, 4, COLOR_PANEL);
}

void updateSensorData(float temp, float humi, float dust, float gas, float batVolt, float current_mA, float batPct) {
  // 1. Ô Nhiệt độ (TEMP)
  tft.fillRect(6, 26, 68, 30, COLOR_BG);
  tft.setTextSize(1); tft.setTextColor(ST7735_WHITE); tft.setCursor(6, 20); tft.print("TEMP");
  tft.setCursor(6, 34); tft.setTextColor(temp > 35.0 ? COLOR_WARN : ST7735_YELLOW);
  tft.print(temp, 1); tft.print(" C");

  // 2. Ô Độ ẩm (HUMI)
  tft.fillRect(86, 26, 68, 30, COLOR_BG);
  tft.setTextColor(ST7735_WHITE); tft.setCursor(86, 20); tft.print("HUMI");
  tft.setCursor(86, 34); tft.setTextColor(ST7735_GREEN);
  tft.print(humi, 1); tft.print(" %");

  // 3. Ô Bụi PM2.5
  tft.fillRect(6, 70, 68, 30, COLOR_BG);
  tft.setTextColor(ST7735_WHITE); tft.setCursor(6, 64); tft.print("PM2.5");
  tft.setCursor(6, 78); tft.setTextColor(dust > 0.15 ? COLOR_WARN : ST7735_CYAN);
  tft.print(dust, 2); tft.setTextSize(1); tft.setCursor(45, 78); tft.print("mg");

  // 4. Ô Khí Gas VOC
  tft.fillRect(86, 70, 68, 30, COLOR_BG);
  tft.setTextColor(ST7735_WHITE); tft.setCursor(86, 64); tft.print("GAS");
  tft.setCursor(86, 78); tft.setTextColor(ST7735_MAGENTA);
  tft.print(gas, 1); tft.setCursor(120, 78); tft.print("kO");

  // 5. Thanh trạng thái Nguồn ở đáy màn hình (Điện áp, Dòng điện và Icon Pin)
  tft.fillRect(6, 110, tft.width() - 12, 12, COLOR_BG);
  tft.setTextSize(1); tft.setTextColor(ST7735_WHITE);
  tft.setCursor(6, 112);
  
  // Hiển thị điện áp và dòng điện
  tft.print((int)(batVolt * 10) / 10.0); tft.print("V ");
  tft.setTextColor(ST7735_CYAN);
  tft.print((int)current_mA); tft.print("mA");

  // Vẽ Icon cục pin 2S tại góc phải thanh đáy
  int batX = 130, batY = 111, batW = 22, batH = 10;
  tft.drawRect(batX, batY, batW, batH, ST7735_WHITE); // Viền pin
  tft.fillRect(batX + batW, batY + 3, 2, 4, ST7735_WHITE); // Núm cực dương pin
  
  // Tính chiều rộng ruột pin theo % của dải 2S (6.0V - 8.4V)
  int fillWidth = (int)((batPct / 100.0) * (batW - 4));
  uint16_t batColor = (batPct < 20) ? COLOR_WARN : ST7735_GREEN;
  
  tft.fillRect(batX + 2, batY + 2, batW - 4, batH - 4, COLOR_BG); // Xóa ruột cũ
  tft.fillRect(batX + 2, batY + 2, fillWidth, batH - 4, batColor); // Vẽ mức pin mới
}

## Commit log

2026-09-21 feat(hardware): integrate KiCad schematics, visual SVG diagram, offline test firmware, and Week 3 progress report
    [1.kicad_pcb, 1.kicad_sch]
2026-09-21 feat(config): integrate KiCad schematic image and configure Firebase RTDB credentials for firmware and dashboard

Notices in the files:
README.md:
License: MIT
